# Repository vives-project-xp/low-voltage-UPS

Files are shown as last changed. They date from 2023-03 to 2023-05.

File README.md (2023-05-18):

# low-voltage-UPS

Project to make a low voltage UPS.
<!-- add better description -->

# Project Repository

This repository contains the source code and documentation for our project.

## Repository Structure

- `case`: Contains files related to the project's case design and 3D models.
- `esp-code`: Contains the code for the ESP micro controller used in the project.
- `frontend`: Contains the web frontend code for the project.
- `home-assistant`: Contains the configuration files for integrating the project with Home Assistant.
- `pcb`: Contains the PCB design files.
- `schemas`: Contains the schema diagrams for the project.

Link to video and ppt:
[Onedrive](https://vivesonline-my.sharepoint.com/:f:/g/personal/r0782899_student_vives_be/ErkIe6ZSpKdGq8MmYVde3NIBA33tiSL_xVnvaDJGF-avBQ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)

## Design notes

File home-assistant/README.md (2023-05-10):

# Home Assistant

## Introduction

This folder contains the files needed to add the low-voltage-UPS to the Home Assistant as a custom component.

To make it easier to read and understand, the documentation is split into three parts:

- [Development](development.md) (for developers)
- [Showcase](showcase.md) (for demonstration purposes)
- [Home Use](home-use.md) (for users)

The component isn't finished yet, so the documentation is still a work in progress.
Information about the component can be found in the [development](development.md) section.

## Images

### Adding the device to Home Assistant

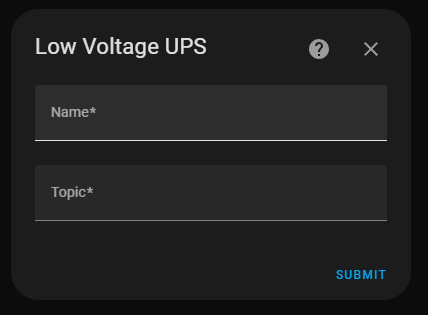
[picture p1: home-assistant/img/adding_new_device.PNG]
adding_new_device


### Overview of the device

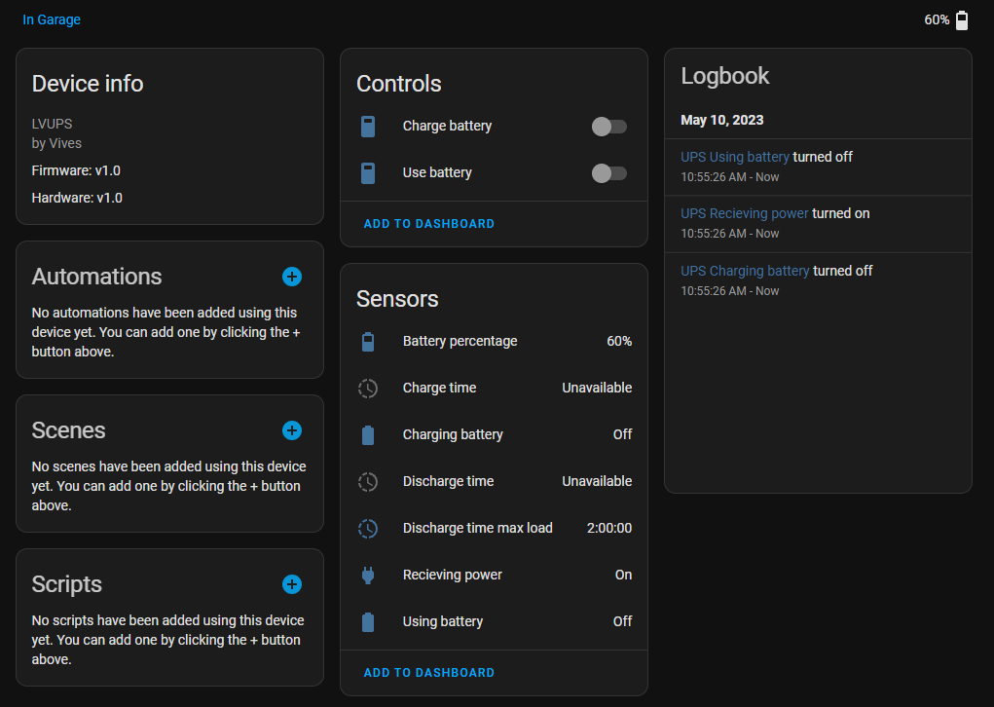
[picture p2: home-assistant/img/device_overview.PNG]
device_overview

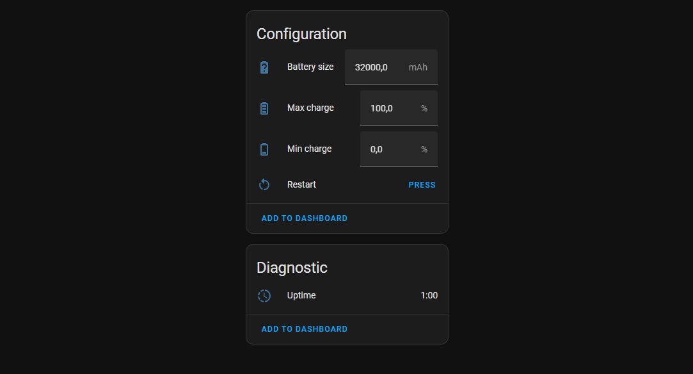
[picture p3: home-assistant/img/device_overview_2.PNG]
device_overview 2


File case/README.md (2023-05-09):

# Case

## Contents

Here is an overview of what this each folder contains:

- blender = the blender project and finished renders/clips
- inventor = the inventor project files for the case
- stl = an stl version of the case parts, useful for 3d printing

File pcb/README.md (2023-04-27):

# Circuit Board

## To do

1. vermogen verbruik van de aangesloten toestel.
2. gaten in de pcb maken.
3. kiezen tussen de batterij en net.
4. io pinnen maken 
5. soon^tm

## Schematic

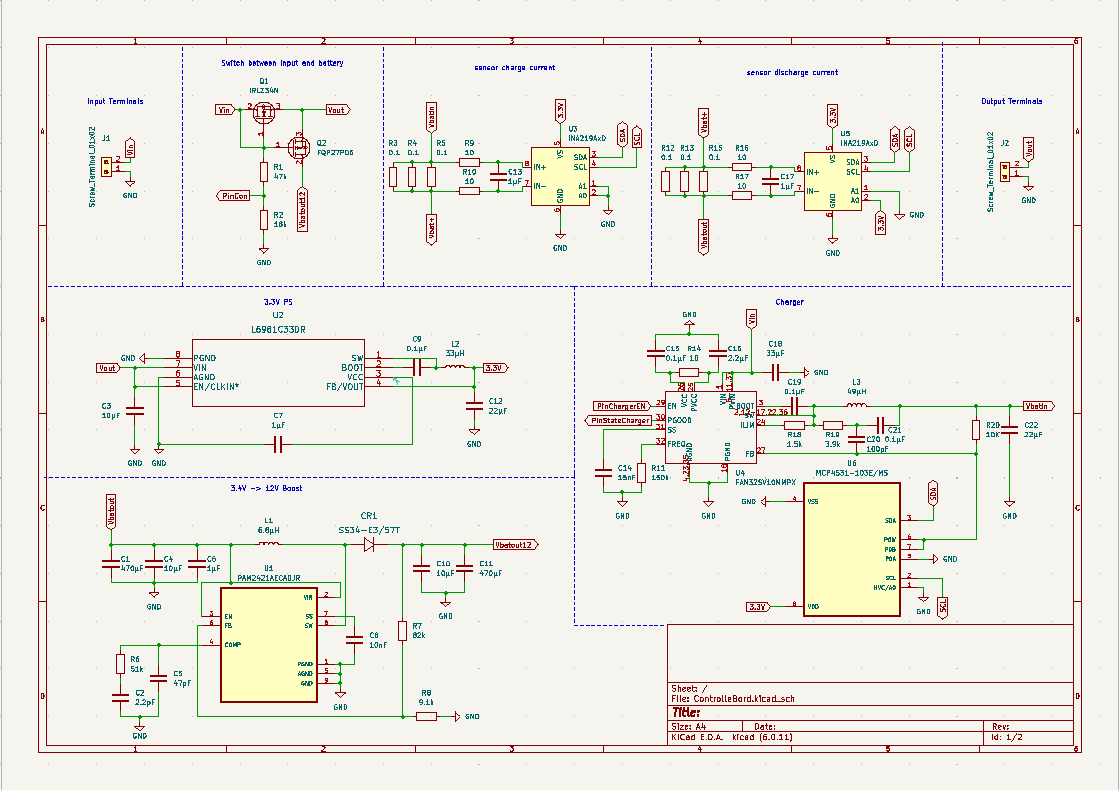
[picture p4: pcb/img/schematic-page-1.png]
SchematicPage1

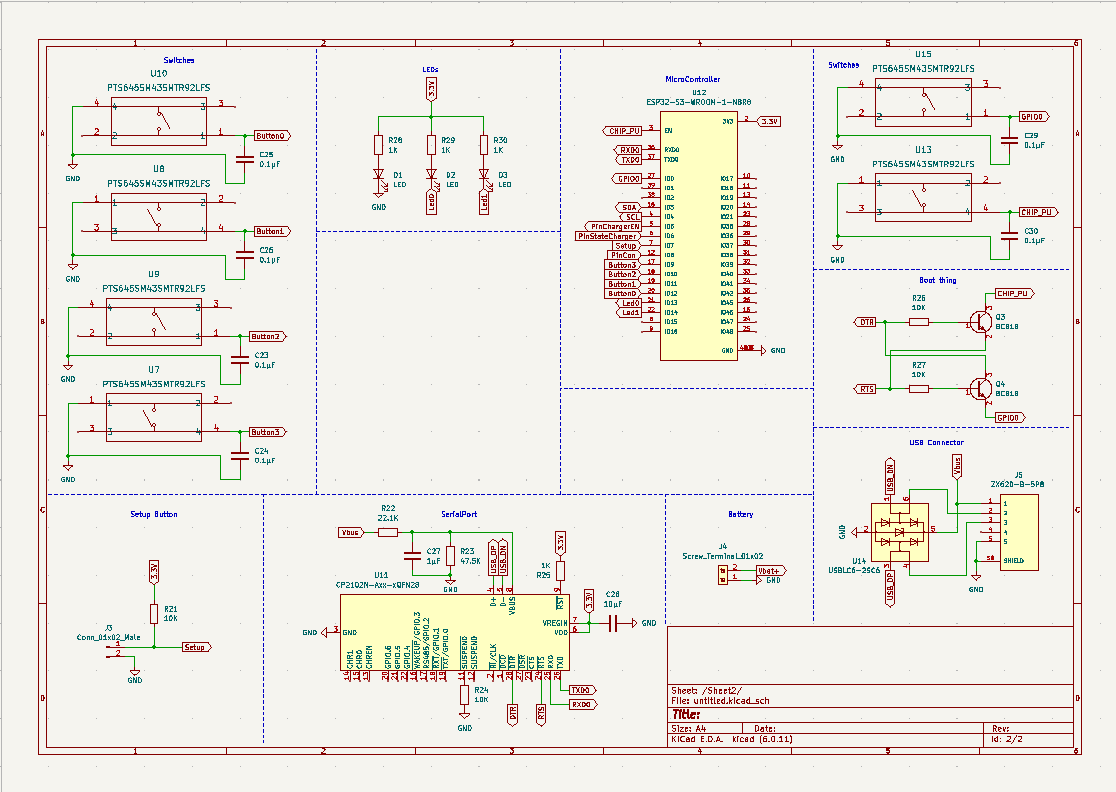
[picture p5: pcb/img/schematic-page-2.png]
SchematicPage2


## PCB

| Front | Back |
|---|---|
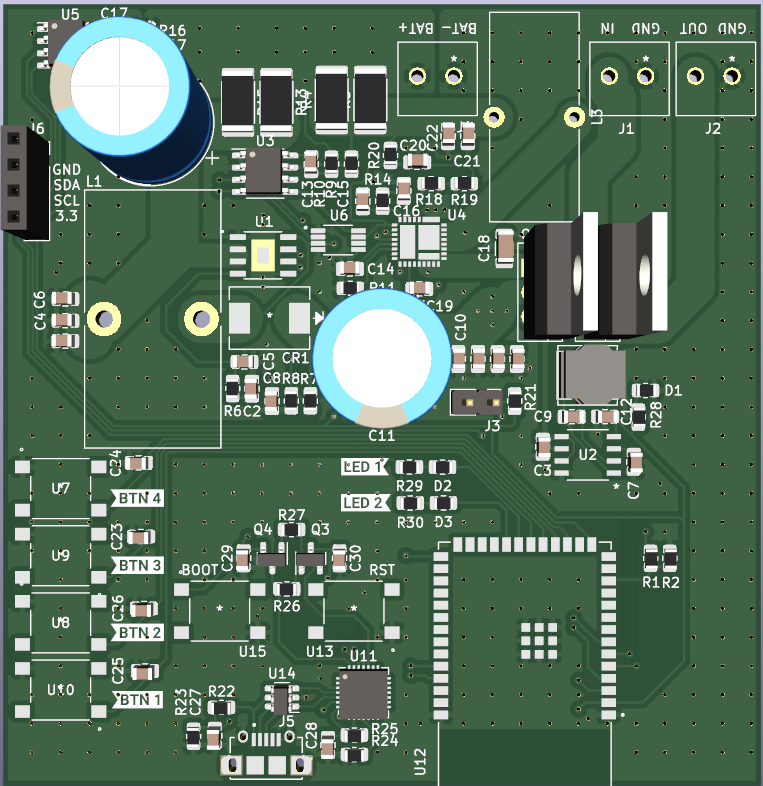
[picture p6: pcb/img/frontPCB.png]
PCB front
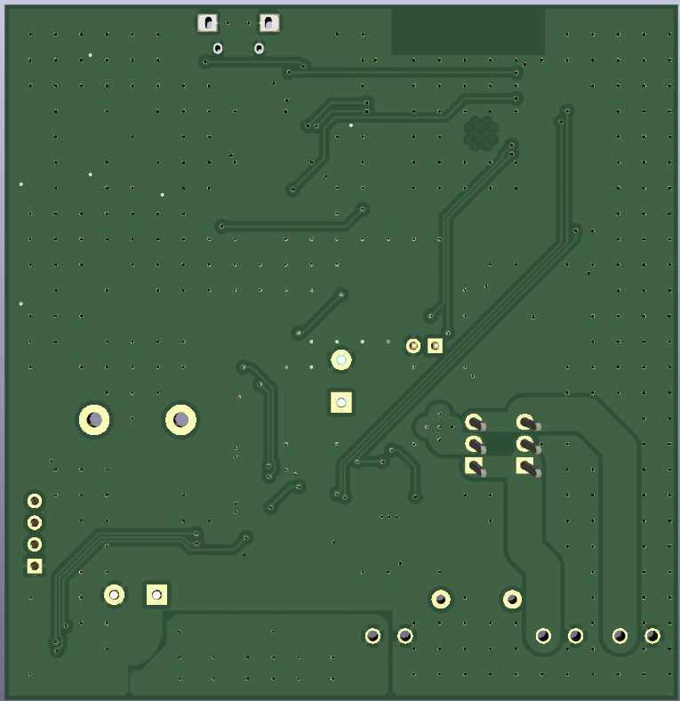
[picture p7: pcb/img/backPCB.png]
PCB Back
|  |  |

## BOM

The BOM or Bill of Materials consists out of a list of all the components with some of theire properties. 

| Designator | Quantity | Description | Footprint | Farnell ordercode | Price / unit |
|---|---|---|---|---|---|
| R25, R28-R30 | 4 | 1 kΩ | 0805 | [2073606](https://be.farnell.com/multicomp/mcmr08x1001ftl/res-1k-1-0-125w-0805-ceramic/dp/2073606) | 0,0165 € |
| R19 | 1 | 47.5 kΩ | 0805 | [2447665](https://be.farnell.com/multicomp/mcwr08x4752ftl/res-47k5-1-0-125w-thick-film/dp/2447665) | 0,0077 € |
| R18 | 1 | 22.1 kΩ | 0805 | [3496003](https://be.farnell.com/yageo/rc0805fr-0722k1l/res-22k1-1-0-125w-0805-thick-film/dp/3496003) | 0,029 € |
| R16, R17, R20, R22, R23 | 5 | 10 kΩ | 0805 | [1612522](https://be.farnell.com/bourns/cr0805-fx-1002elf/res-10k-1-0-125w-0805-thick-film/dp/1612522) | 0,029 € |
| R15 | 1 | 3.9 kΩ | 0805 | [2447654](https://be.farnell.com/multicomp/mcwr08x3901ftl/res-3k9-1-0-125w-thick-film/dp/2447654) | 0,0078 € |
| R14 | 1 | 1.5 kΩ | 0805 | [9333924](https://be.farnell.com/multicomp/mc01w080551k5/res-1k5-5-0-1w-0805-thick-film/dp/9333924) | 0,0153 € |
| R9 | 1 | 150 kΩ | 0805 | [2447573](https://be.farnell.com/multicomp/mcwr08x1503ftl/res-150k-1-0-125w-thick-film/dp/2447573) | 0,0078 € |
| R7, R8, R11-R13 | 5 | 10 Ω | 0805 | [2331768](https://be.farnell.com/te-connectivity/crgh0805j10r/res-10r-5-0-33w-0805-thick-film/dp/2331768) | 0,0132 € |
| R3-R5, R12, R13, R15 | 6 | 0.1 Ω | 0805 | [3994646](https://be.farnell.com/walsin/ww08xr100ftl/res-r100-0-125w-0805-thick-film/dp/3994646?st=shunt%20resistor) | 0,0302 € |
| R5 | 1 | 9.1 kΩ | 0805 | [2447739](https://be.farnell.com/multicomp/mcwr08x9101ftl/res-9k1-1-0-125w-thick-film/dp/2447739) | 0,0078 € |
| R4 | 1 | 82 kΩ | 0805 | [9237860](https://be.farnell.com/yageo/rc0805fr-0782kl/res-82k-1-0-125w-0805-thick-film/dp/9237860) | 0,029 € |
| R3 | 1 | 18 kΩ | 0805 | [2447584](https://be.farnell.com/multicomp/mcwr08x1802ftl/res-18k-1-0-125w-thick-film/dp/2447584) | 0,0078 € |
| R2 | 1 | 47 kΩ | 0805 | [9237836](https://be.farnell.com/yageo/rc0805fr-0747kl/res-47k-1-0-125w-0805-thick-film/dp/9237836) | 0,042 € |
| R1 | 1 | 51 kΩ | 0805 | [2447680](https://be.farnell.com/multicomp/mcwr08x5102ftl/res-51k-1-0-125w-0805-thick-film/dp/2447680) | 0,0081 € |
|---|---|---|---|---|---|
| C2 | 1 | 2.2 pF | 0805 | [3764575](https://be.farnell.com/yageo/cc0805crnpo9bn2r2/cap-2-2pf-50v-mlcc-0805/dp/3764575) | 0,0456 € |
| C5 | 1 | 47 pF | 0805 | [2812152](https://be.farnell.com/wurth-elektronik/885012007032/cap-47pf-25v-5-c0g-np0-0805/dp/2812152) | 0,047 € |
| C6, C7, C13, C17, C23 | 5 | 1μF | 0805 | [3873501](https://be.farnell.com/yageo/cc0805kkx6s8bb105/cap-1uf-25v-mlcc-0805/dp/3873501) | 0,0375 € |
| C8 | 1 | 10 nF | 0805 | [2534062](https://be.farnell.com/wurth-elektronik/885012207066/cap-0-01-f-25v-10-x7r-0805/dp/2534062) | 0,037 € |
| C3, C4, C10, C24 | 4 | 10 μF | 0805 | [3013452](https://be.farnell.com/samsung-electro-mechanics/cl21a106kaynnne/cap-10uf-25v-mlcc-0805/dp/3013452) | 0,073 € |
| C1, C11 | 1 | 470 μF | Radial Leaded | [9451439](https://be.farnell.com/multicomp/mcgpr50v477m13x21/cap-470-f-50v-20/dp/9451439) | 0,546 € |
| C12, C22 | 2 | 22 μF | 0805 | [1907510](https://be.farnell.com/murata/grm21br61e226me44l/cap-22-f-25v-20-x5r-0805/dp/1907510) | 0,178 € |
| C14 | 1 | 15 nF | 0805 | [2812419](https://be.farnell.com/wurth-elektronik/885012207067/cap-0-015-f-25v-10-x7r-0805/dp/2812419) | 0,0344 € |
| C9, C15, C19, C21, C23-C26, C29, C30 | 10 | 0.1 μF | 0805 | [2522443](https://be.farnell.com/kemet/c0805c104z3vactu/cap-0-1-f-25v-y5v-0805/dp/2522443) | 0,033 € |
| C16 | 1 | 2.2 μF | 0805 | [2073606](https://be.farnell.com/samsung-electro-mechanics/cl21a225kafnnne/cap-2-2uf-25v-mlcc-0805/dp/3013458) | 0,049 € |
| C18 | 1 | 33 μF | 1206 | [2525171](https://be.farnell.com/tdk/c3216x5r1e336m160ac/cap-33-f-25v-20-x5r-1206/dp/2525171) | 0,826 € |
| C20 | 1 | 100 pF | 0805 | [2812409](https://be.farnell.com/wurth-elektronik/885012207054/cap-100pf-25v-10-x7r-0805/dp/2812409) | 0,0468 € |
|---|---|---|---|---|---|
| J1, J2, J4 | 3 | 2 ways | screw terminal | [3810178](https://be.farnell.com/amphenol-anytek/yo0221500000g/tb-wire-to-brd-r-a-2way-16awg/dp/3810178) | 0,455 € |
|---|---|---|---|---|---|
| U7-U10, U13, U15 | 6 | Switch | Switch | [2320087](https://be.farnell.com/c-k-components/pts645sm43smtr92lfs/switch-spst-0-05a-12vdc-smd-4/dp/2320087) | 0,25 € |
|---|---|---|---|---|---|
| J5 | 1 | USB connector | USB | [2554980](https://be.farnell.com/hirose-hrs/zx62d-b-5p8-30/micro-usb-2-0-type-b-rcpt-smt/dp/2554980?st=zx62d-b-5p8) | 0,846 € |
| U14 | 1 | ESD Protection Device | SOT-23 | [2290332](https://be.farnell.com/kingbright/kp-2012seck/led-0805-250mcd-orange/dp/2290332) | 0,159 € |
|---|---|---|---|---|---|
| SR1 | 1 | diode | DO-214 | [2101195](https://be.farnell.com/multicomp/ss34a/diode-rectifier-3a-40v-do-214ac/dp/2101195?st=ss34) | 0,401 € |
| D1 - D3 | 3 | led | 0805 | [2101195](https://be.farnell.com/multicomp/ss34a/diode-rectifier-3a-40v-do-214ac/dp/2101195?st=ss34) | 0,401 € |
|---|---|---|---|---|---|
| U6 | 1 | I2c potentiometer | MSOP | [8737606](https://be.farnell.com/microchip/mcp4531-103e-ms/dpot-single-7bit-v-i2c-8msop/dp/1698946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) |0,40 € |
|---|---|---|---|---|---|
| L1 | 1 | 6.8 μH | YUP | [3518424](https://nl.farnell.com/wurth-elektronik/7447720068/inductor-6-8uh-unshielded-3-9a/dp/3518424) | € 0,756 |
| L2 | 1 | 33 μH | YUP | [2061655](https://nl.farnell.com/bourns/srn6045-330m/inductor-33uh-semi-shielded-power/dp/2061655) | € 0,408 |
| L3 | 1 | 49 μH | YUP | [3517136](https://nl.farnell.com/wurth-elektronik/744132/toroidal-inductor-49uh-5-8a-tht/dp/3517136) | € 2,56 |
|---|---|---|---|---|---|
| U3, U5 | 1 | 10 kΩ | SOIC | [3517136](https://be.farnell.com/texas-instruments/ina219bidr/current-power-monitor-11khz-soic/dp/3118166?st=ina219) | 2,96 € |
|---|---|---|---|---|---|
| U1 | 1 | Buck | SOIC | [3755444](https://be.farnell.com/diodes-inc/pam2421aecadjr/dc-dc-conv-boost-520khz-40-to/dp/3755444?st=pam2421) | 0,90 € |
| U2 | 1 | Buck| SOIC | [4064213](https://be.farnell.com/stmicroelectronics/l6981c33dr/dc-dc-conv-sync-buck-400khz-150deg/dp/4064213?st=l6981c) | 3,02 € |
| U4 | 1 | Buck | QFN-34 | [2355372](https://be.farnell.com/onsemi/fan23sv10mmpx/buck-synch-adj-10a-1-5mhz-34pqfn/dp/2355372?st=fan23sv10m) | 1,72 € |
|---|---|---|---|---|---|
| Q2 | 1 | P-kanaal | TO-220 | [8648620](https://be.farnell.com/infineon/irf9540npbf/mosfet-p-100v-23a-to-220/dp/8648620) | 1,55 € |
| Q1 | 1 | N-kanaal | TO-220 | [2547307](https://be.farnell.com/vishay/irfz34pbf/mosfet-n-ch-60v-30a-to-220ab-3/dp/2547307) | 1,96 € |

Total price: 65,03 €

| Designator | Quantity | Description | Footprint | Mouser ordercode | Price / unit |
|---|---|---|---|---|---|
| U12 | 1 | ESP32-S3 | ESP32 | [C2913202](https://www.lcsc.com/product-detail/WiFi-Modules_Espressif-Systems-ESP32-S3-WROOM-1-N16R8_C2913202.html) | € 4.83 |
| U11 | 1 | CP2102NA02GQFN28 | QFN28 | [C964632](https://www.lcsc.com/product-detail/USB-ICs_SILICON-LABS-CP2102N-A02-GQFN28R_C964632.html) | € 2.60 |

Total price: €10.26

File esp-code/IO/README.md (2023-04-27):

# IO documentation

# How some IC`s work.

1. INA219
2. MCP4531 

# The INA219

The INA219 is a ic that Calculates the current and measures the voltage.

## I2C Address

1. The 7 bit address for the charge current sensor is 0b1000000
2. The 7 bit address for the discharge current sensor is 0b1000001

## The data registers

### The Config Register address 0x00.

| MSB | 14 | 13 | 12  | 11  | 10 | 9 | 8 | 7 | 6 | 5 | 4 | 3 | 2 | 1 | LSB |
|-----|----|---|-----|-----|---|---|---|---|---|---|---|---|---|---|---|
| RST | — | BRNG | PG1 | PG0 | BADC 3 | BADC 2 | BADC 1 | BADC 0 | SADC 3 | SADC 2 | SADC 1 | SADC 0 | MODE 2 | MODE 1 | MODE 0 |
| 0 | 0  | 0 | 1 | 0 | 1 | 0 | 0 | 0 | 1 | 0 | 0 | 0 | 1 | 1 | 1 |
| 0 | 0  | 0 | 1 | 0 | 1 | 1 | 0 | 1 | 1 | 1 | 0 | 1 | 1 | 1 | 1 |

We have 2 different values. The first makes only one sample and saves it in the register. The second makes 128 monsters and calculates the average and saves it in the register.

More info see the data sheet.

The values in Hex are 0x1447 or 0x16EF

***

### The Shunt voltage register address 0x01.

| MSB  | 14 | 13 | 12 | 11 | 10 | 9 | 8 | 7 | 6 | 5 | 4 | 3 | 2 | 1 | LSB |
|---|---|---|---|---|---|---|---|---|---|---|---|---|---|---|---|
| SIGN | SIGN | SD13_4 | SD12_4 | SD11_4 | SD10_4 | SD9_4 | SD8_4 | SD7_4 | SD6_4 | SD5_4 | SD4_4 | SD3_4 | SD2_4 | SD1_4 | SD0_4 |

The 2 MSB are the sign. The 14 following bits are the voltage in decimal. To get the real value you need to divide by 100 to get the voltage in mV.

***

### The V-bus register address 0x02.

| MSB  | 14 | 13 | 12  | 11  | 10  | 9 | 8 | 7 | 6 | 5 | 4 | 3 | 2 | 1 | LSB |
|---|---|---|-----|-----|-----|-----|-----|-----|-----|-----|-----|-----|---|---|-----|
| BD12 | BD11 | BD10 | BD9 | BD8 | BD7 | BD6 | BD5 | BD4 | BD3 | BD2 | BD1 | BD0 | — | CNVR | OVF |

The 13 MSB are the voltage value to get the real voltage you need to multiply it with 4mV.

***

### The Power Register address 0x03.

We wont use this one.

***

### The Current Register address 0x04.

| MSB | 14 | 13 | 12 | 11 | 10 | 9 | 8 | 7 | 6 | 5 | 4 | 3 | 2 | 1 | LSB |
|---|---|---|---|---|---|-----|-----|-----|-----|-----|-----|-----|-----|-----|-----|
| CSIGN | CD14 | CD13 | CD12 | CD11 | CD10 | CD9 | CD8 | CD7 | CD6 | CD5 | CD4 | CD3 | CD2 | CD1 | CD0 |

To get the real value you need to multiply by $I_{LSB} =  \tfrac{I_{max}}{2^{15}}$.

In our case is $I_{max}$ 10A so the LSB is $305\mu A$.

***

### The Calibration Register address 0x05.

| MSB  | 14 | 13 | 12 | 11 | 10 | 9 | 8 | 7 | 6 | 5 | 4 | 3 | 2 | 1 | LSB |
|---|---|---|---|---|---|-----|-----|-----|-----|-----|-----|-----|-----|-----|-----|
| FS15 | FS14 | FS13 | FS12 | FS11 | FS10 | FS9 | FS8 | FS7 | FS6 | FS5 | FS4 | FS3 | FS2 | FS1 | FS0 |

To calculate the Calibration Value you need this equation: 

$ Cal = trunc \left( \tfrac{0.04096}{I_{LSB}  * R_{SHUNT}} \right) $

In our case using 2 shunt resistor in parallel and resistent of  $0.01\Omega$ each is the value 0x68DB.

***

# MCP4531

## I2C Address

1. The 7 bit address for the digital potentiometer is 0b0101110

## The data registers

### Wiper 0 0x00

write 10 bits of data MSB wil be ignored only 9 will be saved.

read 2 Bytes and only the last 10 bits have data.

### some screenshots.

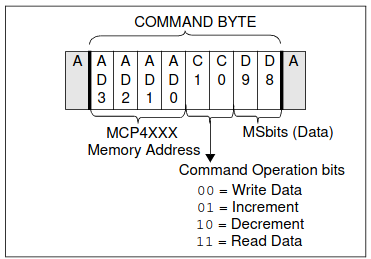
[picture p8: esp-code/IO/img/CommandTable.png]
CommandTable

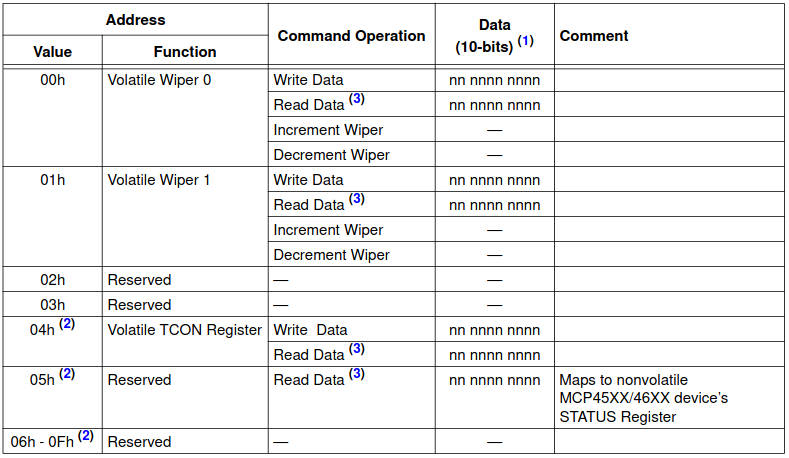
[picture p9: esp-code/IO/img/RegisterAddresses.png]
RegisterAddresses

WriteCommand
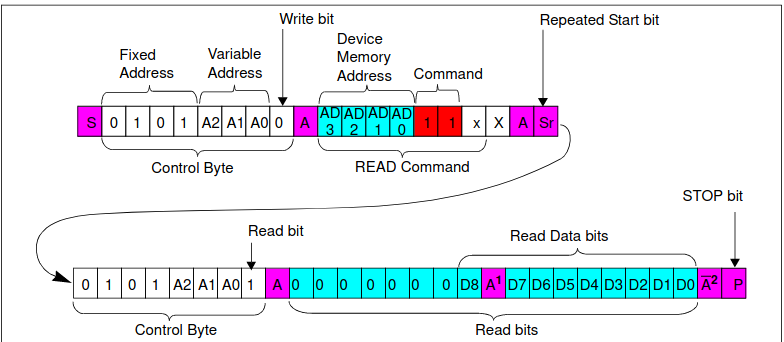
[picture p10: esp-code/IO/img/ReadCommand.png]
ReadCommand


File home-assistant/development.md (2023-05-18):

# Development

## List of contents

1. [Installation](#1-installation)
    1. [Setup Development Environment](#11-setup-development-environment)
    2. [Add the custom component to Home Assistant](#12-add-the-custom-component-to-home-assistant)
        1. [Add the component to the custom_components folder](#121-add-the-component-to-the-custom_components-folder)
        2. [Add the component to the components folder](#122-add-the-component-to-the-components-folder)
2. [Usage](#2-usage)
3. [Testing](#3-testing)
4. [The lvups component](#4-the-lvups-component)
    1. [Device information](#41-device-information)
    2. [File structure and relations](#42-file-structure-and-relations)

## 1. Installation

### 1.1 Setup Development Environment

Before we can start developing, we need our development environment to be set up.  
To do this follow the steps provided by the Home Assistant developer documentation, which can be found [here](https://developers.home-assistant.io/docs/development_environment/).

Once the development environment is set up, we can add our custom component to Home Assistant.

**Note:**  
Don't forget to run the `Install all requirements` task in Visual Studio Code, this will install all the required dependencies for Home Assistant.

### 1.2 Add the custom component to Home Assistant

**There are two ways to do this:**

- Add the component to the custom_components folder (drag and drop, easier for testing)
- Add the component to the components folder (some extra steps, easier for development)

**So what's the difference between these two methods?**  

Both methods will add the component to your Home Assistant installation, but there are some differences.

When you add the component to the custom_components folder, Home Assistant will try to load the component from this folder and expect it to work.
If you have a component that just needs some testing, this is the easiest way to do it.  
The config folder is not part of the Home Assistant repository, because it contains all the user specific configurations.  
This means that if you add your component to this folder, any changes you make to the component will not be tracked by git.

When you add the component to the components folder, Home Assistant will handle the component as a built-in component.
If you're developing a component that you want to add to Home Assistant, this is the way to go.
This gives you the benefits of the Home Assistant development tools, like translation, unit tests, etc.
But also means that your code needs to follow the Home Assistant Rules and Guidelines before you can commit it to your fork.

#### 1.2.1 Add the component to the custom_components folder

1. Go to the config folder of your Home Assistant installation and create a new folder called `custom_components` (if it doesn't exist already).
2. In this folder just drag and drop the content of the `component` folder from this repository.

That's it, the component is now added to your Home Assistant installation.

#### 1.2.2 Add the component to the components folder

1. Open a terminal in the root of your Home Assistant installation.
2. Run the following command: `python3 -m script.scaffold integration`. (This script will create a new component in the components folder.)
3. Fill in the following information when prompted (for this component):
    - What is the domain?
        > `lvups`

    - What is the name of your integration?
        > `Low Voltage UPS`

    - What is your GitHub handle?
        > `??` (your GitHub username, @username)

    - What PyPI package and version do you depend on? Leave blank for none.
        > (We are not using any dependencies, so leave this blank)

    - How will your integration gather data?
        > `local_push` (We update the state when the device pushes an update, so we don't need to poll the device)

    - Does Home Assistant need the user to authenticate to control the device/service? (yes/no) [yes]
        > `no` (We don't need to authenticate to control the device)

    - Is the device/service discoverable on the local network? (yes/no) [no]
        > `no` (The device is not discoverable on the local network)

    - Is this a helper integration? (yes/no) [no]
        > `no` (This is not a helper integration)

    - Can the user authenticate the device using OAuth2? (yes/no) [no]
        > `no` (We are using mqtt, so we don't need OAuth2)

4. Wait for the script to finish. (Home Assistant will create all the necessary files for you)
5. Open the folder `homeassistant/components/lvups` in your favorite editor.
6. Replace the contents of the folder with the contents of the `component/lvups` folder from this repository.

That's it, the component is now added to your Home Assistant installation.

## 2. Usage

Now that the component is added to your Home Assistant installation, you can start using/developing it.  
More information about developing custom components can be found [here](https://developers.home-assistant.io/docs/creating_component_index).

## 3. Testing

When you want to test the code, you can spin up a Home Assistant instance with the custom component installed.  
If your using Visual Studio Code, you can simply press `F5` to start a Home Assistant instance.

**Note:**  
When this is the first time you are starting Home Assistant, it will require you to do the initial setup, just like a normal Home Assistant installation.  
This means that you will need to create a user, set a password, etc.

## 4. The lvups component

### 4.1 Device information

The lvups device has the following attributes:

controls:

- `Charge battery`: A switch that can be used to tell the device it should charge the battery. (default: `off`)
- `Use battery`: A switch that can be used to tell the device it should use the battery, when recieving grid power. (default: `off`)

sensors:

- `Battery percentage`: A sensor that shows the current battery percentage.
- `Charge time`: A sensor that shows the time left until the battery is fully charged, estimate. (When charging)
- `Discharge time`: A sensor that shows the time left until the battery is fully discharged, estimate. (When discharging)
- `Discharge time max load`: A sensor that shows the time left until the battery is fully discharged, estimate on max load. (Always shown)
- `Charging battery`: A sensor that shows if the battery is currently charging.
- `Using battery`: A sensor that shows if the battery is currently being used.
- `Recieving power`: A sensor that shows if the device is currently recieving power from the grid.

Configuration:

- `Battery size`: The capacity of the battery in mAh. (default: `0`)
- `Max charge`: The maximum percentage the battery can be charged to. (default: `100`)
- `Min charge`: The minimum percentage the battery can be discharged to. (default: `0`)
- `Restart`: A button that can be used to restart the device.

Diagnostic:

- `Uptime`: The time the device has been running, in `hours:minutes:seconds` format.

### 4.2 File structure and relations

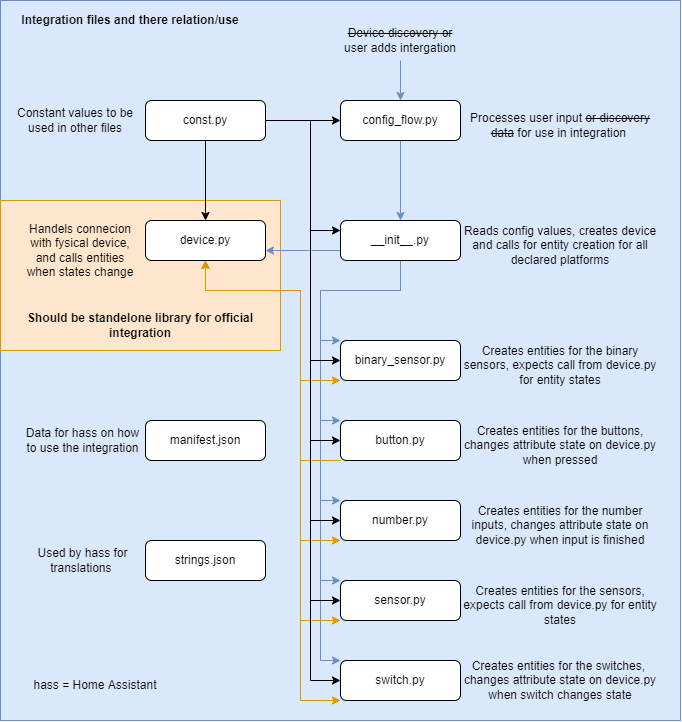
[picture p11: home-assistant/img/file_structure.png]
schema of the file structure


### 4.2 Todo

- [ ] Add mqtt discovery
- [ ] Add LWT (last will and testament)
- [ ] Add unit tests (for device and config flow)
- [ ] Change translations (on/off -> charging/discharging, etc.)
- [ ] Add more sensors, switches, etc. (depends on the hardware)
- [ ] Move device code to a library (as needed by the Home Assistant Rules and Guidelines)
- [ ] Make the code comply with the Home Assistant Rules and Guidelines (so it may someday be added to Home Assistant)

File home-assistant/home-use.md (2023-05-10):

# Home Use

## List of contents

1. [Installation](#1-installation)
    1. [Setup Home Assistant](#11-setup-home-assistant)
    2. [Add the custom component](#12-add-the-custom-component)
        1. [Home Assistant Container](#121-home-assistant-container)
        2. [Home Assistant Operating System](#122-home-assistant-operating-system)
    3. [Add lvups device to Home Assistant](#13-add-lvups-device-to-home-assistant)
2. [Usage](#2-usage)

## 1. Installation

### 1.1 Setup Home Assistant

For installation instructions, see the [home assistant documentation](https://www.home-assistant.io/installation/).

**Note:**
Make sure you also have mqtt running either in a container or as an addon.

### 1.2 Add the custom component

#### 1.2.1 Home Assistant Container

If your running Home Assistant Container, you can add the component to your installation by following these steps:

1. Make sure Home Assistant is not running.
2. Make sure you have cloned this repository to your local machine and are in the home-assistant directory.
3. Run the following command:
    ```docker cp ./component/ <container_name>:/config/custom_components/```.
    (replace `<container_name>` with the name of your Home Assistant Container)
4. Start Home Assistant.

That's it, the component is now added to your Home Assistant installation.

#### 1.2.2 Home Assistant Operating System

If your running Home Assistant Operating System, you can add the component to your installation by following these steps:

1. In your Home Assisant instance, go to Settings > Add-ons.
2. Under the Official add-ons section, you will find the File editor add-on.
3. Click on File editor and click on Install. When the installation is complete, the UI will go to the add-on details page for the file editor.
4. Now start the add-on by clicking on Start.
5. Open the user interface by clicking on Open Web UI.
6. In the File editor, go to the config folder of your Home Assistant installation and create a new folder called `custom_components` (if it doesn't exist already).
7. In this folder just drag and drop the content of the `component` folder from this repository.
8. Restart Home Assistant.

That's it, the component is now added to your Home Assistant installation.

### 1.3 Add lvups device to Home Assistant

Now you can add a lvups device to your Home Assistant installation.
This can be done by going to Setting > Devices & services and clicking on the Add Integration button.

Now search for lvups and click on the lvups integration.
Fill in the required information and click on Submit.

That's it, the lvups device is now added to your Home Assistant installation.

**Note:**
Make sure you have added your mqtt broker to Home Assistant before adding the lvups device else it will not work. For more info about this, see the [MQTT documentation](https://www.home-assistant.io/integrations/mqtt/).

## 2. Usage

Now that we have a working Home Assistant installation with the lvups component installed, we can start using it.

### 2.1 Device info

The lvups device has the following attributes:

controls:

- `Charge battery`: A switch that can be used to tell the device it should charge the battery. (default: `off`)
- `Use battery`: A switch that can be used to tell the device it should use the battery, when recieving grid power. (default: `off`)

sensors:

- `Battery percentage`: A sensor that shows the current battery percentage.
- `Charge time`: A sensor that shows the time left until the battery is fully charged, estimate. (When charging)
- `Discharge time`: A sensor that shows the time left until the battery is fully discharged, estimate. (When discharging)
- `Discharge time max load`: A sensor that shows the time left until the battery is fully discharged, estimate on max load. (Always shown)
- `Charging battery`: A sensor that shows if the battery is currently charging.
- `Using battery`: A sensor that shows if the battery is currently being used.
- `Recieving power`: A sensor that shows if the device is currently recieving power from the grid.

Configuration:

- `Battery size`: The capacity of the battery in mAh. (default: `0`)
- `Max charge`: The maximum percentage the battery can be charged to. (default: `100`)
- `Min charge`: The minimum percentage the battery can be discharged to. (default: `0`)
- `Restart`: A button that can be used to restart the device.

Diagnostic:

- `Uptime`: The time the device has been running, in `hours:minutes:seconds` format.

### 2.2 Automation examples

Here are some automation examples that you can use:

- Get a notification when there is no power going to the device (possible grid power loss):

    ```text
        trigger:
            - UPS recieving power: 'off'
        action:
            - Call notify service with message: 'Grid power loss'
    ```

- Charge bettery when solar power is avaialble: (example made using cdem for getting data from smartmeter)

    ```text
        trigger:
            - cdem power production: '> 0'
        condition:
            - UPS battery percentage: '< 100'
        action:
            - UPS charge battery: 'on'
    ```

- Use battery when grid power uses high tarif: (also using the cdem component)

    ```text
        trigger:
            - cdem tarif: 'high'
        condition:
            - UPS battery percentage: '> 50'
        action:
            - UPS use battery: 'on'
    ```

## 3. Troubleshooting

- When performing a firmware update, you will need to reload the lvups device in Home Assistant to see the new firmware version.

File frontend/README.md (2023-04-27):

# Nuxt 3 Minimal Starter

Look at the [Nuxt 3 documentation](https://nuxt.com/docs/getting-started/introduction) to learn more.

## Preview

Current version of the deployed application is available at [https://ups.robcocquyt.be](https://ups.robcocquyt.be/)

## Setup

Make sure to install the dependencies using npm:

```bash
npm install
```

## Development Server

Start the development server on http://localhost:3000

```bash
npm run dev
```

## Production

Build the application for production:

```bash
npm run build
```

Locally preview production build:

```bash
npm run preview
```

Check out the [deployment documentation](https://nuxt.com/docs/getting-started/deployment) for more information.

## Used Packages

- [Nuxt 3](https://v3.nuxtjs.org/)
- [Tailwind css](https://tailwindcss.com)
- [Daisy UI](https://daisyui.com/)
- [Nuxt Icon](https://github.com/nuxt-modules/icon)

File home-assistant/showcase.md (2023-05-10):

# Showcase

## List of contents

1. [Installation](#1-installation)
    1. [Requirements](#11-requirements)
    2. [Setup containers](#12-setup-containers)
    3. [Configure Home Assistant](#13-configure-home-assistant)

2. [Usage](#2-usage)

## 1. Installation

### 1.1 Requirements

Before you can run the showcase, you need to install the following dependencies:

- Docker

### 1.2 Setup containers

To setup the containers, follow the steps below:

1. Make sure docker is running.
2. Open a terminal in the `showcase` directory.
3. Run the following command in the terminal:

    ```bash
    docker-compose up
    ```

4. Wait for the containers to start.
5. Now we copy the component to the Home Assistant container, run the following command in the terminal:

    ```bash
    docker cp ../component/ homeassistant:/config/custom_components
    ```

6. Restart the Home Assistant container.

### 1.3 Configure Home Assistant

After the containers are started, got to the Home Assistant web interface using the following [link](http://localhost:8123).  
Now you can configure Home Assistant to your liking, for more info about this, see the [Home Assistant documentation](https://www.home-assistant.io/docs/).  
We also need to add our mqtt broker to Home Assistant, for more info about this, see the [MQTT documentation](https://www.home-assistant.io/integrations/mqtt/).  
The mqtt broker is available at `mosquitto:1883`.

## 2. Usage

After setting up the environment, you should have a working Home Assistant installation with the low-voltage-UPS component installed.
Now you simply need to add a low-voltage-UPS device to your Home Assistant installation, for more info about this, see the [Home Assistant documentation](https://www.home-assistant.io/docs/configuration/devices/).

For automation examples, please look at the [Home-Use](home-use.md) section.

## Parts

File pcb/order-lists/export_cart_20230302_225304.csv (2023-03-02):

LCSC Part Number | Manufacture Part Number | Manufacturer | Package | Customer # | Description | RoHS | Order Qty. | Min\Mult Order Qty. | Unit Price | Order Price | Product Link
C2913202 | ESP32-S3-WROOM-1-N16R8 | Espressif Systems | SMD,18x25.5mm |  | SMD,18x25.5mm WiFi Modules ROHS | yes | 1 | 1 | 4.8293 | 4.83 | https://assets.lcsc.com/images/lcsc/96x96/20230123_Espressif-Systems-ESP32-S3-WROOM-1-N16R8_C2913202_front.jpg
C964632 | CP2102N-A02-GQFN28R | SILICON LABS | QFN-28-EP(5x5) |  | QFN-28-EP(5x5) USB ICs ROHS | yes | 1 | 1 | 2.5955 | 2.60 | https://assets.lcsc.com/images/lcsc/96x96/20230202_SILICON-LABS-CP2102N-A02-GQFN28R_C964632_front.jpg

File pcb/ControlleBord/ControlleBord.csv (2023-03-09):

Source: | /home/gibi500/Vives/projectWeek/pcb/ControlleBord/ControlleBord.kicad_sch
Date: | Thu 02 Mar 2023 10:11:45 AM CET
Tool: | Eeschema (6.0.11)
Generator: | /usr/share/kicad/plugins/bom_csv_grouped_by_value.py
Component Count: | 75
Individual Components:
Item | Qty | Reference(s) | Value | LibPart | Footprint | Datasheet | MANUFACTURER | MAXIMUM_PACKAGE_HEIGHT | MF | Manufacturer | PARTREV | Package | SNAPEDA_PN | STANDARD
 |  | C1 | 470μF | Device:C | Capacitor_THT:CP_Radial_D13.0mm_P5.00mm | ~
 |  | C2 | 2.2pF | Device:C | Capacitor_SMD:C_0805_2012Metric | ~
 |  | C3 | 10μF | Device:C | Capacitor_SMD:C_0805_2012Metric | ~
 |  | C4 | 10μF | Device:C | Capacitor_SMD:C_0805_2012Metric | ~
 |  | C5 | 47pF | Device:C | Capacitor_SMD:C_0805_2012Metric | ~
 |  | C6 | 1μF | Device:C | Capacitor_SMD:C_0805_2012Metric | ~
 |  | C7 | 1μF | Device:C | Capacitor_SMD:C_0805_2012Metric | ~
 |  | C8 | 10nF | Device:C | Capacitor_SMD:C_0805_2012Metric | ~
 |  | C9 | 100nF | Device:C | Capacitor_SMD:C_0805_2012Metric | ~
 |  | C10 | 10μF | Device:C | Capacitor_SMD:C_0805_2012Metric | ~
 |  | C11 | 470μF | Device:C | Capacitor_THT:CP_Radial_D13.0mm_P5.00mm | ~
 |  | C12 | 22μF | Device:C | Capacitor_SMD:C_0805_2012Metric | ~
 |  | C13 | 1μF | Device:C | Capacitor_SMD:C_0805_2012Metric | ~
 |  | C14 | 15nF | Device:C | Capacitor_SMD:C_0805_2012Metric | ~
 |  | C15 | 0.1μF | Device:C | Capacitor_SMD:C_0805_2012Metric | ~
 |  | C16 | 2.2μF | Device:C | Capacitor_SMD:C_0805_2012Metric | ~
 |  | C17 | 1μF | Device:C | Capacitor_SMD:C_0805_2012Metric | ~
 |  | C18 | 33μF | Device:C | Capacitor_SMD:C_1206_3216Metric | ~
 |  | C19 | 0.1μF | Device:C | Capacitor_SMD:C_0805_2012Metric | ~
 |  | C20 | 100pF | Device:C | Capacitor_SMD:C_0805_2012Metric | ~
 |  | C21 | 0.1μF | Device:C | Capacitor_SMD:C_0805_2012Metric | ~
 |  | C22 | 22μF | Device:C | Capacitor_SMD:C_0805_2012Metric | ~
 |  | C23 | 1μF | Device:C | Capacitor_SMD:C_0805_2012Metric | ~
 |  | C24 | 10μF | Device:C | Capacitor_SMD:C_0805_2012Metric | ~
 |  | C25 | 0.1μF | Device:C | Capacitor_SMD:C_0805_2012Metric | ~
 |  | C26 | 0.1μF | Device:C | Capacitor_SMD:C_0805_2012Metric | ~
 |  | CR1 | SS34-E3/57T | 2023-02-22_21-35-58:SS34-E3{slash}57T | footprints1.0:SS34-E3&slash_57T
 |  | D1 | PESD5V0L1BA,115 | Diode:ESD9B5.0ST5G | Diode_SMD:D_SOD-323 | https://www.onsemi.com/pub/Collateral/ESD9B-D.PDF
 |  | D2 | PESD5V0L1BA,115 | Diode:ESD9B5.0ST5G | Diode_SMD:D_SOD-323 | https://www.onsemi.com/pub/Collateral/ESD9B-D.PDF
 |  | D3 | PESD5V0L1BA,115 | Diode:ESD9B5.0ST5G | Diode_SMD:D_SOD-323 | https://www.onsemi.com/pub/Collateral/ESD9B-D.PDF
 |  | J1 | Screw_Terminal_01x02 | Connector:Screw_Terminal_01x02 | footprints3.0:YO0221500000G | ~
 |  | J2 | Screw_Terminal_01x02 | Connector:Screw_Terminal_01x02 | footprints3.0:YO0221500000G | ~
 |  | J3 | Conn_01x02_Male | Connector:Conn_01x02_Male | Connector_PinHeader_2.54mm:PinHeader_1x02_P2.54mm_Vertical | ~
 |  | J4 | Screw_Terminal_01x02 | Connector:Screw_Terminal_01x02 | footprints3.0:YO0221500000G | ~
 |  | J5 | ZX62D-B-5P8 | ZX62D-B-5P8:ZX62D-B-5P8 | Kicad:HRS_ZX62D-B-5P8 |  |  |  | Hirose Electric |  | N/A |  |  | Manufacturer Recommendations
 |  | L1 | 6.8μH | Device:L | Inductor_THT:L_Toroid_Vertical_L26.7mm_W14.0mm_P10.16mm_Pulse_D | ~
 |  | L2 | 33μH | Device:L | Inductor_SMD:L_Bourns_SRN6045TA | ~
 |  | L3 | 49μH | Device:L | Inductor_THT:L_Toroid_Vertical_L21.6mm_W9.1mm_P8.40mm_Bourns_5700 | ~
 |  | Q1 | IRLZ34N | Transistor_FET:IRLZ34N | Package_TO_SOT_THT:TO-220-3_Vertical | http://www.infineon.com/dgdl/irlz34npbf.pdf?fileId=5546d462533600a40153567206892720
 |  | Q2 | FQP27P06 | Transistor_FET:FQP27P06 | Package_TO_SOT_THT:TO-220-3_Vertical | https://www.onsemi.com/pub/Collateral/FQP27P06-D.PDF
 |  | Q3 | BC818 | Transistor_BJT:BC818 | Package_TO_SOT_SMD:SOT-23 | https://www.onsemi.com/pub/Collateral/BC818-D.pdf
 |  | Q4 | BC818 | Transistor_BJT:BC818 | Package_TO_SOT_SMD:SOT-23 | https://www.onsemi.com/pub/Collateral/BC818-D.pdf
 |  | R1 | 51k | Device:R | Resistor_SMD:R_0805_2012Metric | ~
 |  | R2 | 47k | Device:R | Resistor_SMD:R_0805_2012Metric | ~
 |  | R3 | 18k | Device:R | Resistor_SMD:R_0805_2012Metric | ~
 |  | R4 | 82k | Device:R | Resistor_SMD:R_0805_2012Metric | ~
 |  | R5 | 9.1k | Device:R | Resistor_SMD:R_0805_2012Metric | ~
 |  | R6 | R_Shunt | Device:R_Shunt | Package_TO_SOT_THT:TO-220-2_Vertical | ~
 |  | R7 | 10 | Device:R | Resistor_SMD:R_0805_2012Metric | ~
 |  | R8 | 10 | Device:R | Resistor_SMD:R_0805_2012Metric | ~
 |  | R9 | 150k | Device:R | Resistor_SMD:R_0805_2012Metric | ~
 |  | R10 | R_Shunt | Device:R_Shunt | Package_TO_SOT_THT:TO-220-2_Vertical | ~
 |  | R11 | 10 | Device:R | Resistor_SMD:R_0805_2012Metric | ~
 |  | R12 | 10 | Device:R | Resistor_SMD:R_0805_2012Metric | ~
 |  | R13 | 10 | Device:R | Resistor_SMD:R_0805_2012Metric | ~
 |  | R14 | 1.5k | Device:R | Resistor_SMD:R_0805_2012Metric | ~
 |  | R15 | 3.9k | Device:R | Resistor_SMD:R_0805_2012Metric | ~
 |  | R16 | 10K | Device:R | Resistor_SMD:R_0805_2012Metric | ~
 |  | R17 | 10K | Device:R | Resistor_SMD:R_0805_2012Metric | ~
 |  | R18 | 22.1K | Device:R | Resistor_SMD:R_0805_2012Metric | ~
 |  | R19 | 47.5K | Device:R | Resistor_SMD:R_0805_2012Metric | ~
 |  | R20 | 10K | Device:R | Resistor_SMD:R_0805_2012Metric | ~
 |  | R21 | 1K | Device:R | Resistor_SMD:R_0805_2012Metric | ~
 |  | R22 | 10K | Device:R | Resistor_SMD:R_0805_2012Metric | ~
 |  | R23 | 10K | Device:R | Resistor_SMD:R_0805_2012Metric | ~
 |  | U1 | PAM2421AECADJR | PAM2421AECADJR:PAM2421AECADJR | Kicad:SOIC127P600X175-8N |  |  |  |  | Diodes Inc. |  | SOIC127P600X175-8N
 |  | U2 | L6981C33DR | 2023-02-22_21-42-58:L6981C33DR | footprints2.0:L6981C33DR
 |  | U3 | INA219AxD | Sensor_Energy:INA219AxD | Package_SO:SOIC-8_3.9x4.9mm_P1.27mm | http://www.ti.com/lit/ds/symlink/ina219.pdf
 |  | U4 | FAN32SV10MMPX | homeMade:FAN32SV10MMPX | footprints1.0:FAN23SV10M
 |  | U5 | INA219AxD | Sensor_Energy:INA219AxD | Package_SO:SOIC-8_3.9x4.9mm_P1.27mm | http://www.ti.com/lit/ds/symlink/ina219.pdf
 |  | U6 | MCP4531-103E/MS | MCP4531-103E_MS:MCP4531-103E{slash}MS | Kicad:SOP65P490X110-8N
 |  | U7 | CP2102N-Axx-xQFN28 | Interface_USB:CP2102N-Axx-xQFN28 | Package_DFN_QFN:QFN-28-1EP_5x5mm_P0.5mm_EP3.35x3.35mm | https://www.silabs.com/documents/public/data-sheets/cp2102n-datasheet.pdf
 |  | U8 | ESP32-S3-WROOM-2-N32R8V | ESP32-S3-WROOM-2-N32R8V:ESP32-S3-WROOM-2-N32R8V | Kicad:XCVR_ESP32-S3-WROOM-2-N32R8V |  | Espressif | 3.25mm |  |  | 1.0 |  | ESP32-S3-WROOM-2-N32R8V | Manufacturer Recommendations
 |  | U9 | PTS645SM43SMTR92LFS | 2023-03-02_01-59-27:PTS645SM43SMTR92LFS | SWITCH_43SMTR92LFS
 |  | U10 | PTS645SM43SMTR92LFS | 2023-03-02_01-59-27:PTS645SM43SMTR92LFS | SWITCH_43SMTR92LFS
Collated Components:
Item | Qty | Reference(s) | Value | LibPart | Footprint | Datasheet | MANUFACTURER | MAXIMUM_PACKAGE_HEIGHT | MF | Manufacturer | PARTREV | Package | SNAPEDA_PN | STANDARD
1 | 2 | C1, C11 | 470μF | Device:C | Capacitor_THT:CP_Radial_D13.0mm_P5.00mm | ~
2 | 1 | C2 | 2.2pF | Device:C | Capacitor_SMD:C_0805_2012Metric | ~
3 | 4 | C3, C4, C10, C24 | 10μF | Device:C | Capacitor_SMD:C_0805_2012Metric | ~
4 | 1 | C5 | 47pF | Device:C | Capacitor_SMD:C_0805_2012Metric | ~
5 | 5 | C6, C7, C13, C17, C23 | 1μF | Device:C | Capacitor_SMD:C_0805_2012Metric | ~
6 | 1 | C8 | 10nF | Device:C | Capacitor_SMD:C_0805_2012Metric | ~
7 | 1 | C9 | 100nF | Device:C | Capacitor_SMD:C_0805_2012Metric | ~
8 | 2 | C12, C22 | 22μF | Device:C | Capacitor_SMD:C_0805_2012Metric | ~
9 | 1 | C14 | 15nF | Device:C | Capacitor_SMD:C_0805_2012Metric | ~
10 | 5 | C15, C19, C21, C25, C26 | 0.1μF | Device:C | Capacitor_SMD:C_0805_2012Metric | ~
11 | 1 | C16 | 2.2μF | Device:C | Capacitor_SMD:C_0805_2012Metric | ~
12 | 1 | C18 | 33μF | Device:C | Capacitor_SMD:C_1206_3216Metric | ~
13 | 1 | C20 | 100pF | Device:C | Capacitor_SMD:C_0805_2012Metric | ~
14 | 1 | CR1 | SS34-E3/57T | 2023-02-22_21-35-58:SS34-E3{slash}57T | footprints1.0:SS34-E3&slash_57T
15 | 3 | D1, D2, D3 | PESD5V0L1BA,115 | Diode:ESD9B5.0ST5G | Diode_SMD:D_SOD-323 | https://www.onsemi.com/pub/Collateral/ESD9B-D.PDF
16 | 3 | J1, J2, J4 | Screw_Terminal_01x02 | Connector:Screw_Terminal_01x02 | footprints3.0:YO0221500000G | ~
17 | 1 | J3 | Conn_01x02_Male | Connector:Conn_01x02_Male | Connector_PinHeader_2.54mm:PinHeader_1x02_P2.54mm_Vertical | ~
18 | 1 | J5 | ZX62D-B-5P8 | ZX62D-B-5P8:ZX62D-B-5P8 | Kicad:HRS_ZX62D-B-5P8 |  |  |  | Hirose Electric |  | N/A |  |  | Manufacturer Recommendations
19 | 1 | L1 | 6.8μH | Device:L | Inductor_THT:L_Toroid_Vertical_L26.7mm_W14.0mm_P10.16mm_Pulse_D | ~
20 | 1 | L2 | 33μH | Device:L | Inductor_SMD:L_Bourns_SRN6045TA | ~
21 | 1 | L3 | 49μH | Device:L | Inductor_THT:L_Toroid_Vertical_L21.6mm_W9.1mm_P8.40mm_Bourns_5700 | ~
22 | 1 | Q1 | IRLZ34N | Transistor_FET:IRLZ34N | Package_TO_SOT_THT:TO-220-3_Vertical | http://www.infineon.com/dgdl/irlz34npbf.pdf?fileId=5546d462533600a40153567206892720
23 | 1 | Q2 | FQP27P06 | Transistor_FET:FQP27P06 | Package_TO_SOT_THT:TO-220-3_Vertical | https://www.onsemi.com/pub/Collateral/FQP27P06-D.PDF
24 | 2 | Q3, Q4 | BC818 | Transistor_BJT:BC818 | Package_TO_SOT_SMD:SOT-23 | https://www.onsemi.com/pub/Collateral/BC818-D.pdf
25 | 1 | R1 | 51k | Device:R | Resistor_SMD:R_0805_2012Metric | ~
26 | 1 | R2 | 47k | Device:R | Resistor_SMD:R_0805_2012Metric | ~
27 | 1 | R3 | 18k | Device:R | Resistor_SMD:R_0805_2012Metric | ~
28 | 1 | R4 | 82k | Device:R | Resistor_SMD:R_0805_2012Metric | ~
29 | 1 | R5 | 9.1k | Device:R | Resistor_SMD:R_0805_2012Metric | ~
30 | 2 | R6, R10 | R_Shunt | Device:R_Shunt | Package_TO_SOT_THT:TO-220-2_Vertical | ~
31 | 5 | R7, R8, R11, R12, R13 | 10 | Device:R | Resistor_SMD:R_0805_2012Metric | ~
32 | 1 | R9 | 150k | Device:R | Resistor_SMD:R_0805_2012Metric | ~
33 | 1 | R14 | 1.5k | Device:R | Resistor_SMD:R_0805_2012Metric | ~
34 | 1 | R15 | 3.9k | Device:R | Resistor_SMD:R_0805_2012Metric | ~
35 | 5 | R16, R17, R20, R22, R23 | 10K | Device:R | Resistor_SMD:R_0805_2012Metric | ~
36 | 1 | R18 | 22.1K | Device:R | Resistor_SMD:R_0805_2012Metric | ~
37 | 1 | R19 | 47.5K | Device:R | Resistor_SMD:R_0805_2012Metric | ~
38 | 1 | R21 | 1K | Device:R | Resistor_SMD:R_0805_2012Metric | ~
39 | 1 | U1 | PAM2421AECADJR | PAM2421AECADJR:PAM2421AECADJR | Kicad:SOIC127P600X175-8N |  |  |  |  | Diodes Inc. |  | SOIC127P600X175-8N
40 | 1 | U2 | L6981C33DR | 2023-02-22_21-42-58:L6981C33DR | footprints2.0:L6981C33DR
41 | 2 | U3, U5 | INA219AxD | Sensor_Energy:INA219AxD | Package_SO:SOIC-8_3.9x4.9mm_P1.27mm | http://www.ti.com/lit/ds/symlink/ina219.pdf
42 | 1 | U4 | FAN32SV10MMPX | homeMade:FAN32SV10MMPX | footprints1.0:FAN23SV10M
43 | 1 | U6 | MCP4531-103E/MS | MCP4531-103E_MS:MCP4531-103E{slash}MS | Kicad:SOP65P490X110-8N
44 | 1 | U7 | CP2102N-Axx-xQFN28 | Interface_USB:CP2102N-Axx-xQFN28 | Package_DFN_QFN:QFN-28-1EP_5x5mm_P0.5mm_EP3.35x3.35mm | https://www.silabs.com/documents/public/data-sheets/cp2102n-datasheet.pdf
45 | 1 | U8 | ESP32-S3-WROOM-2-N32R8V | ESP32-S3-WROOM-2-N32R8V:ESP32-S3-WROOM-2-N32R8V | Kicad:XCVR_ESP32-S3-WROOM-2-N32R8V |  | Espressif | 3.25mm |  |  | 1.0 |  | ESP32-S3-WROOM-2-N32R8V | Manufacturer Recommendations
46 | 2 | U9, U10 | PTS645SM43SMTR92LFS | 2023-03-02_01-59-27:PTS645SM43SMTR92LFS | SWITCH_43SMTR92LFS

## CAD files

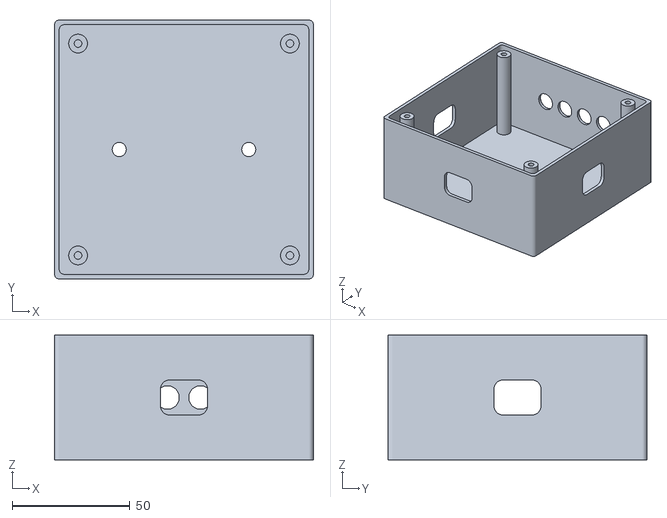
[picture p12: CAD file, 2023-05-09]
case/stl/Base.stl
110.0 x 110.0 x 53.0

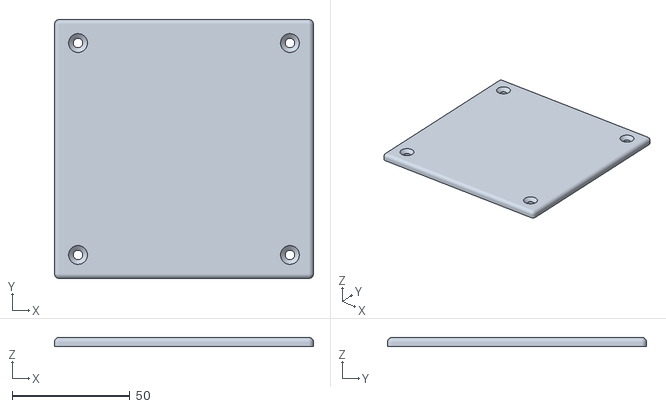
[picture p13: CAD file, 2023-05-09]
case/stl/Lid.stl
110.0 x 110.0 x 4.00

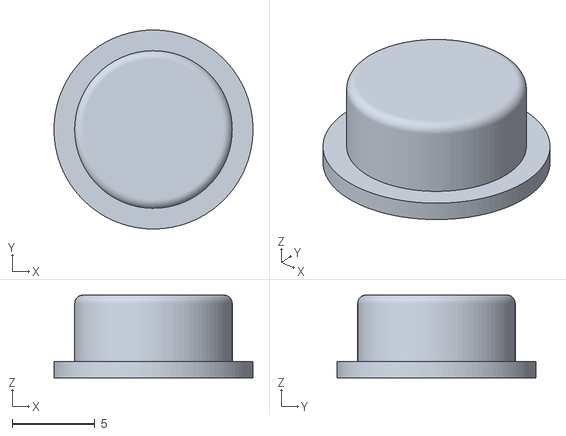
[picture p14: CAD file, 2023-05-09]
case/stl/Button.stl
12.0 x 12.0 x 5.00

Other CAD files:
case/inventor/Base.ipt
case/inventor/Button.ipt
case/inventor/Lid.ipt
case/inventor/OldVersions/Base.0016.ipt
case/inventor/OldVersions/Button.0001.ipt
case/inventor/OldVersions/Lid.0008.ipt
case/inventor/OldVersions/PCB.0001.ipt
case/inventor/OldVersions/case.0005.iam
case/inventor/PCB.ipt
case/inventor/case.iam

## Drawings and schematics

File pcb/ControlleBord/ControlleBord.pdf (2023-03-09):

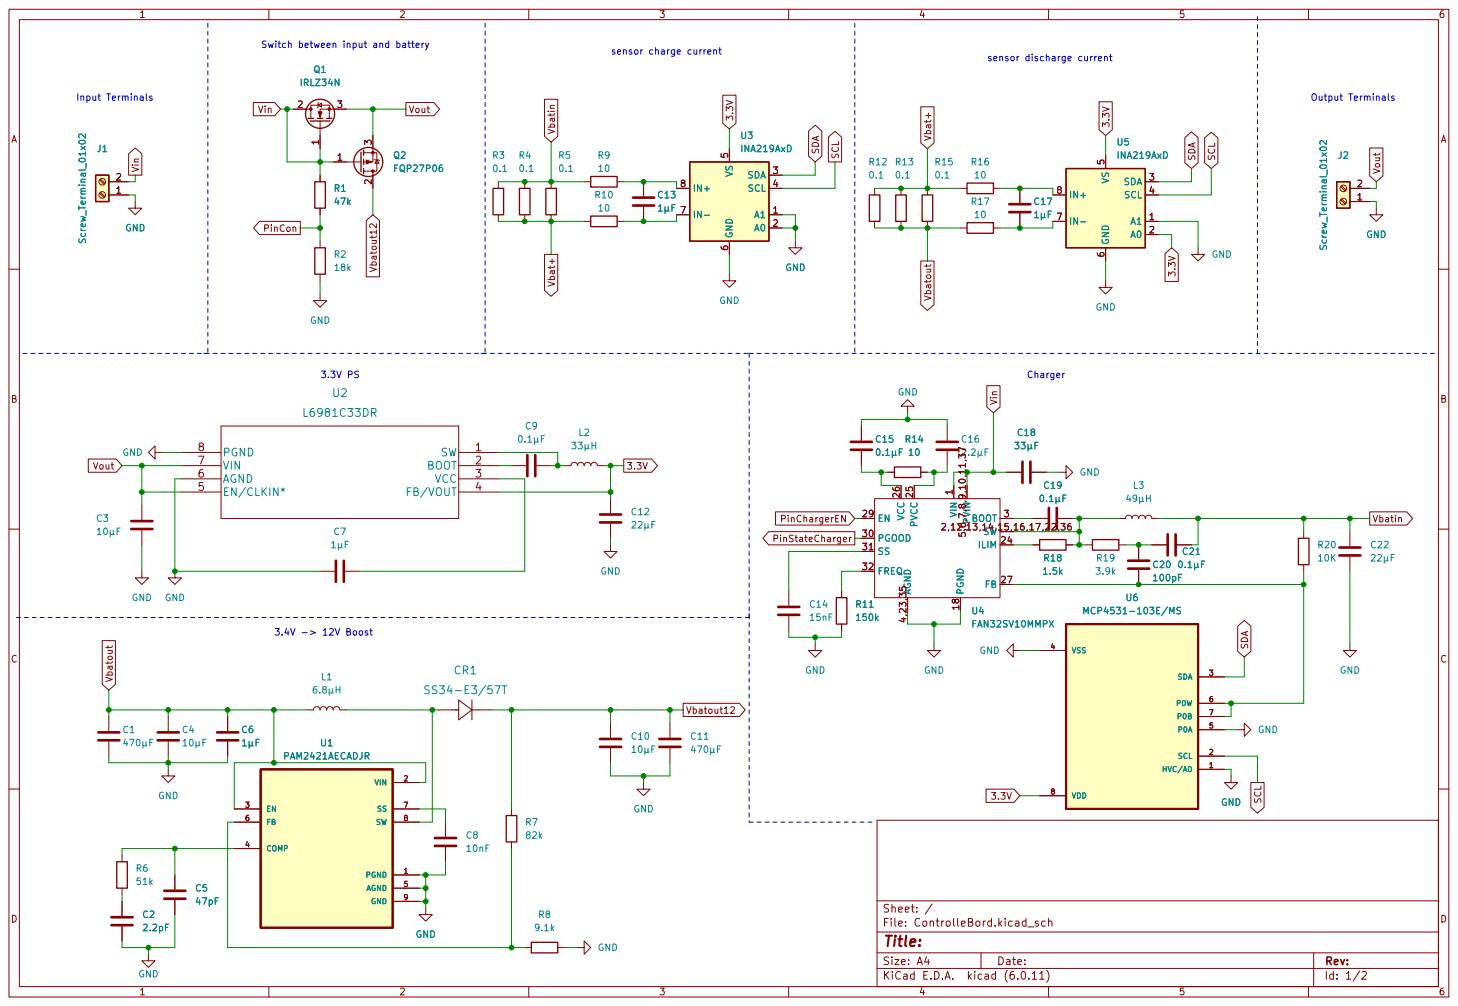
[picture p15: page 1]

Id: 1/2 Title: File: ControlleBord.kicad_sch Sheet: /

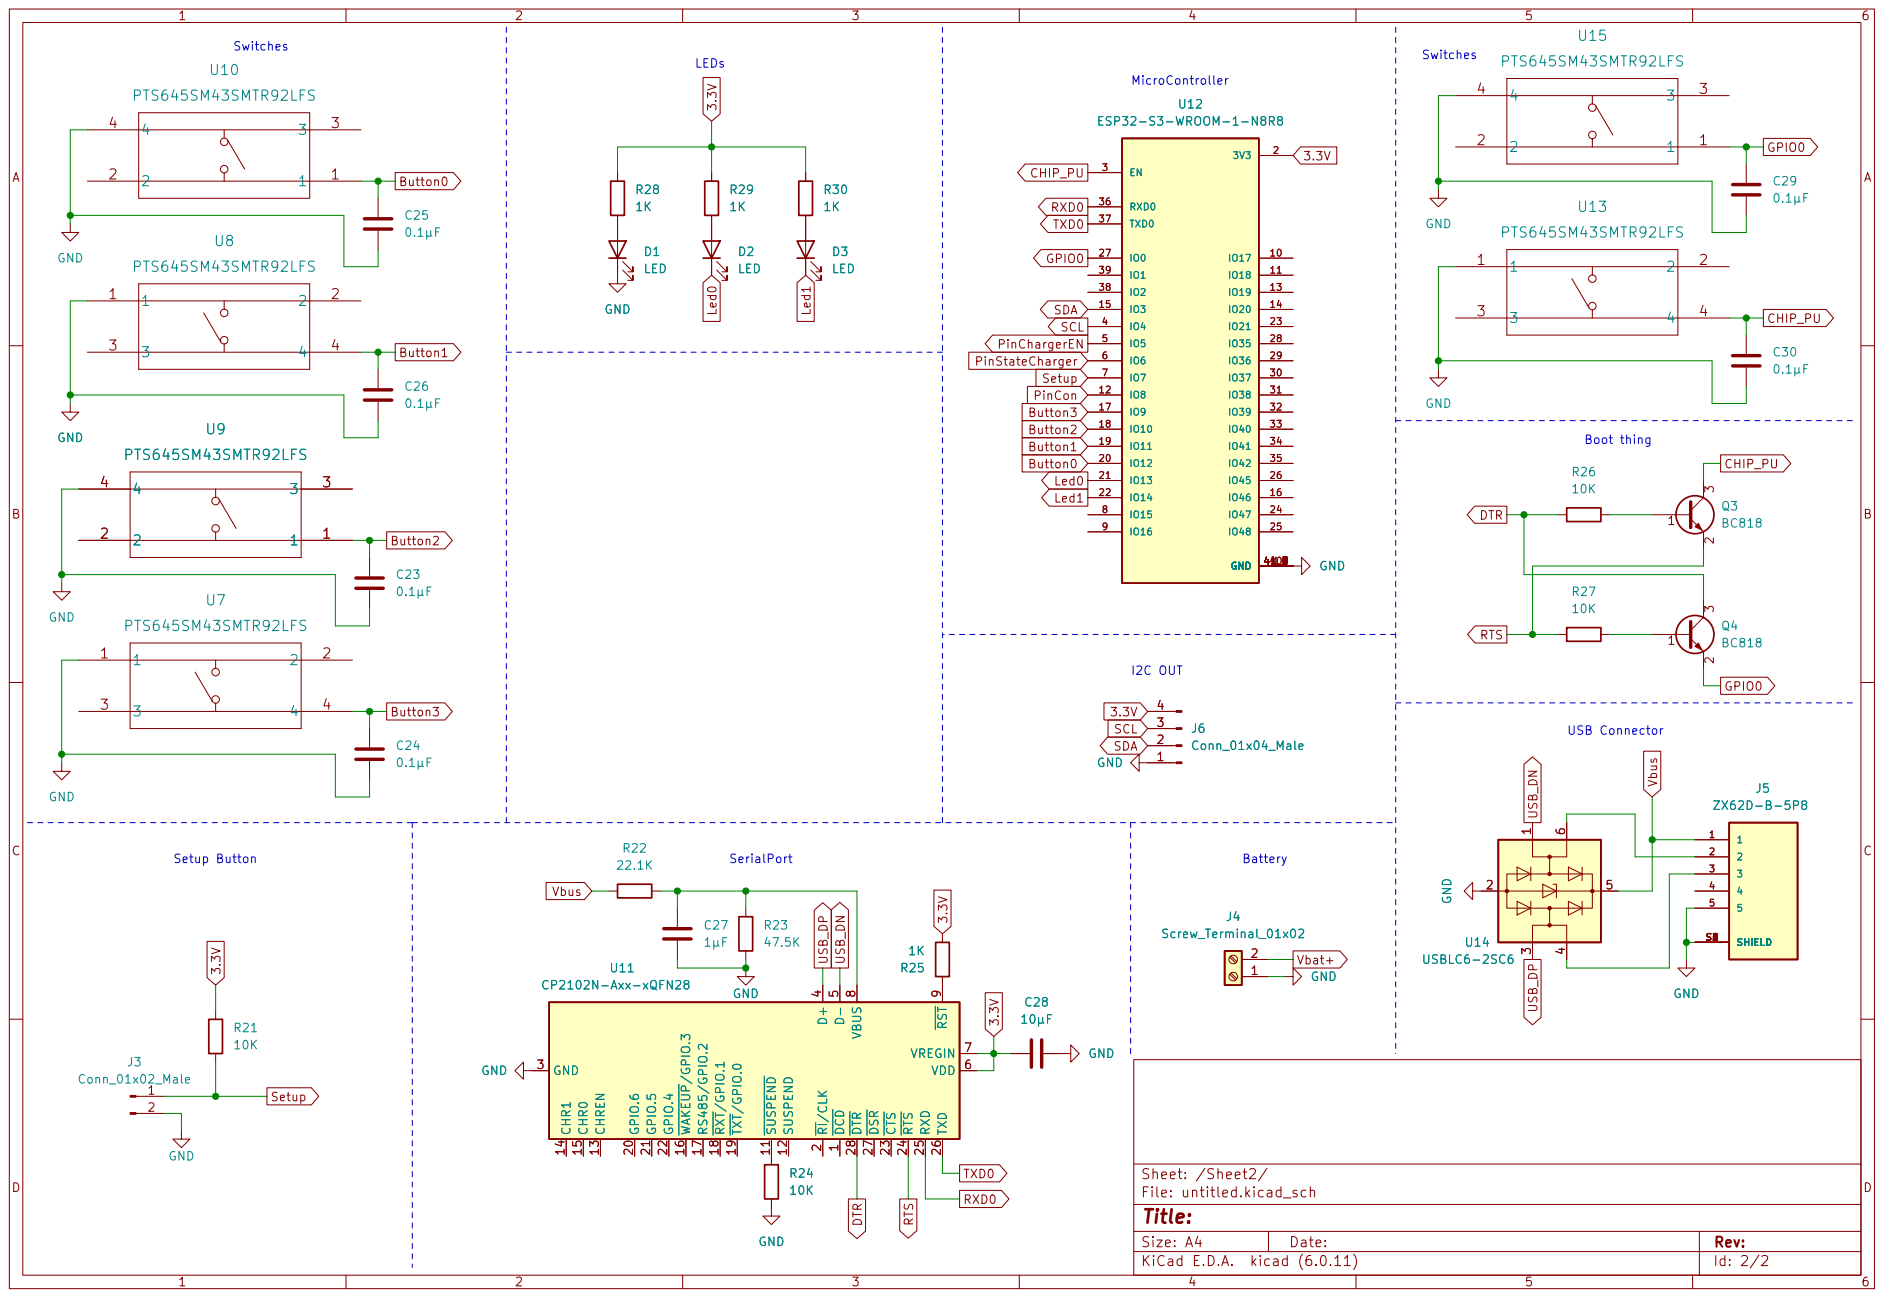
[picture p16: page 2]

2 GPIO.6 20 GPIO.5 21 GPIO.4 22 ~{CTS} 23 ~{RTS} 24 RXD 25 TXD 26 ~{DSR} 27 ~{DTR} 28 GND 3 D+

Id: 2/2 Title: File: untitled.kicad_sch Sheet: /Sheet2/

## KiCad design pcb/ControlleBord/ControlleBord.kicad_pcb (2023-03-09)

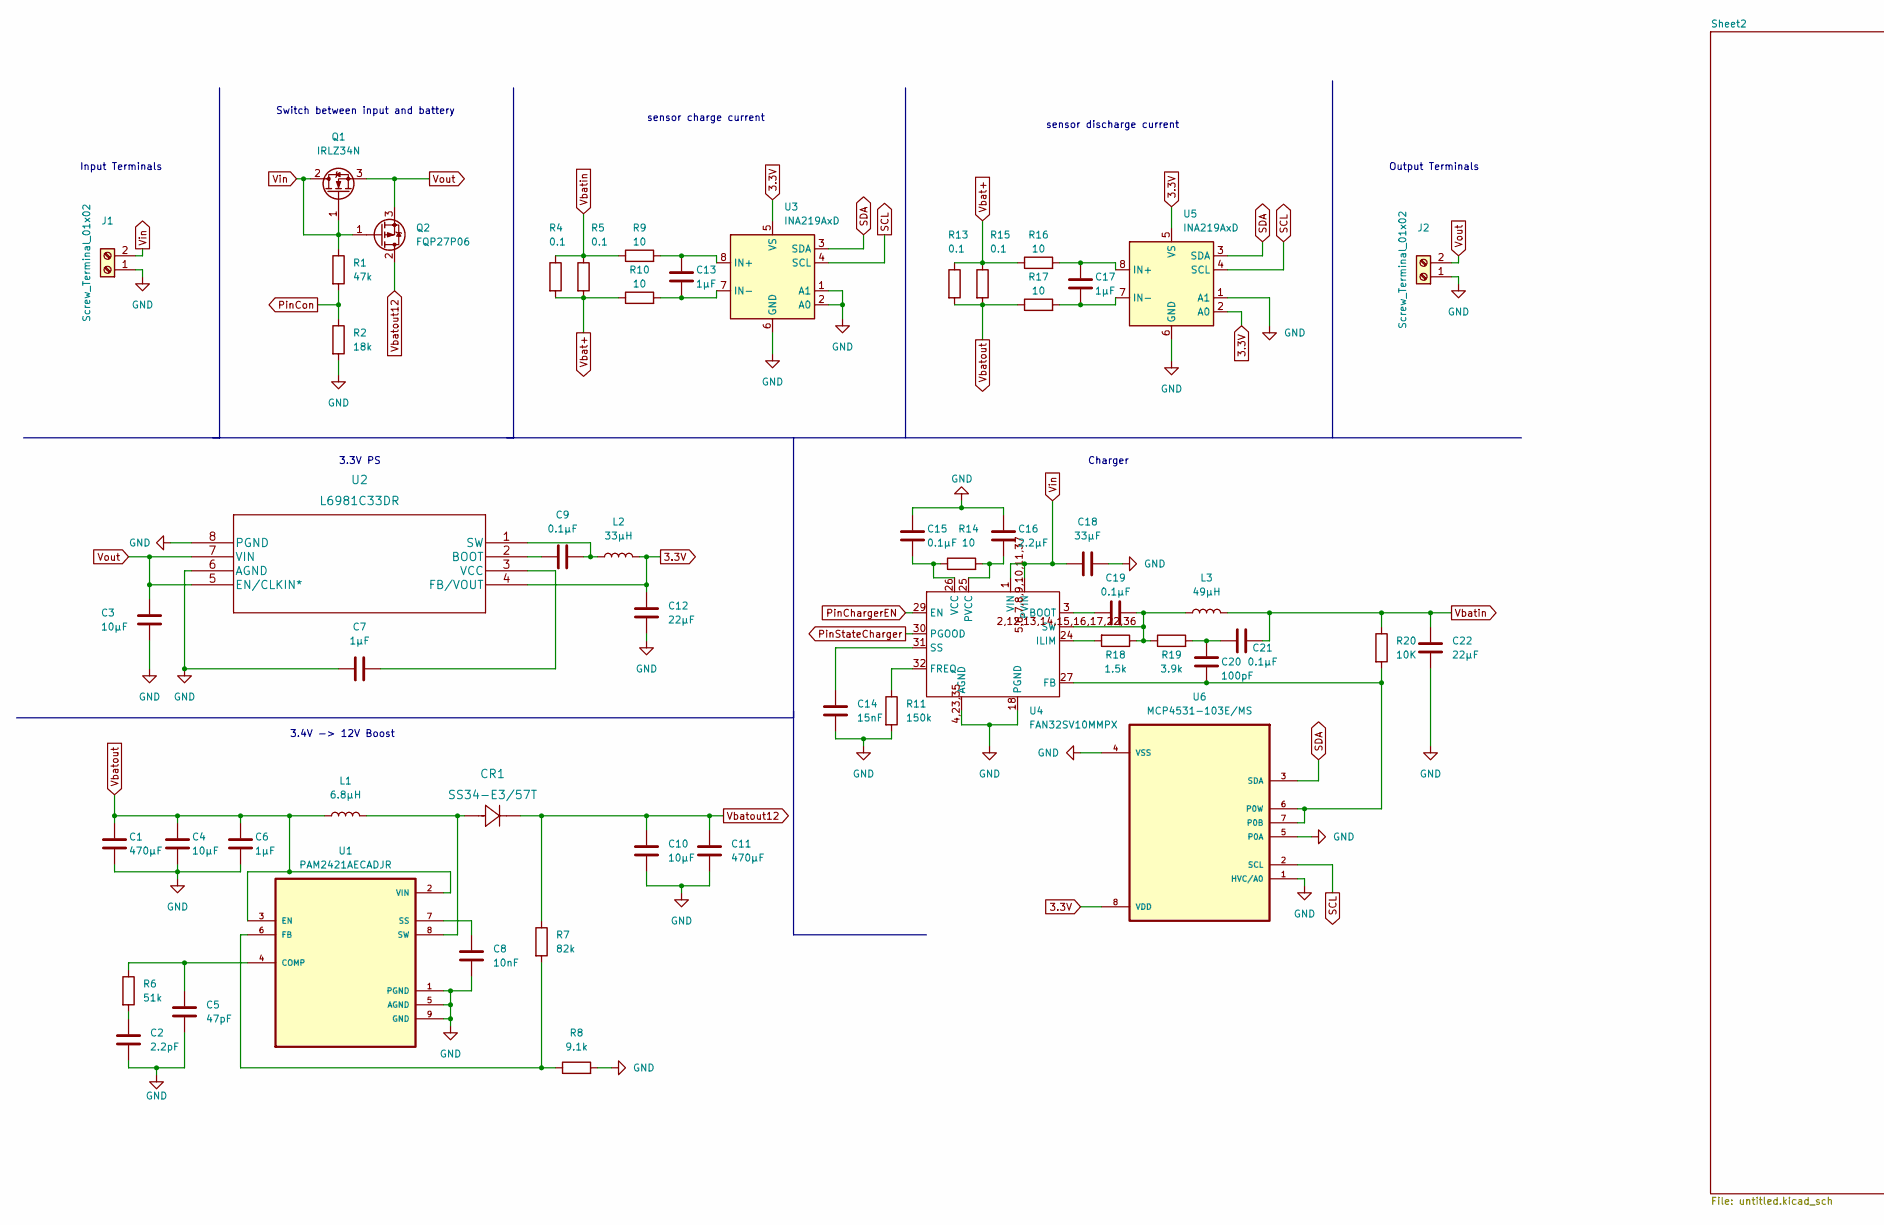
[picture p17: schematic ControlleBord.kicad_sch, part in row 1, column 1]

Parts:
C1, C11: 470μF; CP_Radial_D13.0mm_P5.00mm
C2: 2.2pF; C_0805_2012Metric
C3, C4, C10: 10μF; C_0805_2012Metric
C5: 47pF; C_0805_2012Metric
C6, C7, C13, C17: 1μF; C_0805_2012Metric
C8: 10nF; C_0805_2012Metric
C9, C15, C19, C21: 0.1μF; C_0805_2012Metric
C12, C22: 22μF; C_0805_2012Metric
C14: 15nF; C_0805_2012Metric
C16: 2.2μF; C_0805_2012Metric
C18: 33μF; C_1206_3216Metric
C20: 100pF; C_0805_2012Metric
CR1: SS34-E3/57T; SS34-E3&slash_57T
J1, J2: Screw_Terminal_01x02; YO0221500000G
L1: 6.8μH; L_Toroid_Vertical_L26.7mm_W14.0mm_P10.16mm_Pulse_D
L2: 33μH; L_Bourns_SRN6045TA
L3: 49μH; L_Toroid_Vertical_L21.6mm_W9.1mm_P8.40mm_Bourns_5700
Q1: IRLZ34N; TO-220-3_Vertical
Q2: FQP27P06; TO-220-3_Vertical
R1: 47k; R_0805_2012Metric
R2: 18k; R_0805_2012Metric
R4, R5, R13, R15: 0.1; R_2512_6332Metric
R6: 51k; R_0805_2012Metric
R7: 82k; R_0805_2012Metric
R8: 9.1k; R_0805_2012Metric
R9, R10, R14, R16, R17: 10; R_0805_2012Metric
R11: 150k; R_0805_2012Metric
R18: 1.5k; R_0805_2012Metric
R19: 3.9k; R_0805_2012Metric
R20: 10K; R_0805_2012Metric
U1: PAM2421AECADJR; SOIC127P600X175-8N
U2: L6981C33DR
U3, U5: INA219AxD; SOIC-8_3.9x4.9mm_P1.27mm
U4: FAN32SV10MMPX; FAN23SV10M
U6: MCP4531-103E/MS; SOP65P490X110-8N

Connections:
3.3V: C12.1, L2.2, U2.4 (FB/VOUT), U3.5 (VS), U5.2 (A0), U5.5 (VS), U6.8 (VDD); also elsewhere on the board
GND: C1.2, C2.2, C3.2, C4.2, C5.2, C6.2, C7.1, C8.2, C10.2, C11.2, C12.2, C14.2, C15.1, C16.1, C18.2, C22.2, J1.1, J2.1, R2.2, R8.2, R11.2, U1.1 (PGND), U1.5 (AGND), U1.9 (GND), U2.6 (AGND), U2.8 (PGND), U3.1 (A1), U3.2 (A0), U3.6 (GND), U4.4,23,35 (AGND), U4.18 (PGND), U5.1 (A1), U5.6 (GND), U6.1 (HVC/A0), U6.4 (VSS), U6.5 (P0A); also elsewhere on the board
unnamed: C2.1, R6.2
unnamed: C5.1, R6.1, U1.4 (COMP)
unnamed: C7.2, U2.3 (VCC)
unnamed: C8.1, U1.7 (SS)
unnamed: C9.1, U2.2 (BOOT)
unnamed: C9.2, L2.1, U2.1 (SW)
unnamed: C13.1, R9.2, U3.8 (IN+)
unnamed: C13.2, R10.2, U3.7 (IN-)
unnamed: C14.1, U4.31 (SS)
unnamed: C15.2, R14.1, U4.26 (VCC)
unnamed: C16.2, R14.2, U4.25 (PVCC)
unnamed: C17.1, R16.2, U5.8 (IN+)
unnamed: C17.2, R17.2, U5.7 (IN-)
unnamed: C19.1, U4.3 (BOOT)
unnamed: C19.2, L3.1, R18.1, R19.1, U4.2,12,13,14,15,16,17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 (SW)
unnamed: C20.1, C21.1, R19.2
unnamed: C20.2, R20.2, U4.27 (FB), U6.6 (P0W), U6.7 (P0B)
unnamed: CR1.2, L1.2, U1.8 (SW)
unnamed: R7.2, R8.1, U1.6 (FB)
unnamed: R11.1, U4.32 (FREQ)
unnamed: R18.2, U4.24 (ILIM)
PinChargerEN: U4.29 (EN); also elsewhere on the board
PinCon: R1.2, R2.1; also elsewhere on the board
PinStateCharger: U4.30 (PGOOD); also elsewhere on the board
SCL: U3.4 (SCL), U5.4 (SCL), U6.2 (SCL); also elsewhere on the board
SDA: U3.3 (SDA), U5.3 (SDA), U6.3 (SDA); also elsewhere on the board
Vbat+: R4.2, R5.2, R10.1, R13.1, R15.1, R16.1; also elsewhere on the board
Vbatin: C21.2, C22.1, L3.2, R4.1, R5.1, R9.1, R20.1
Vbatout: C1.1, C4.1, C6.1, L1.1, R13.2, R15.2, R17.1, U1.2 (VIN), U1.3 (EN); also elsewhere on the board
Vbatout12: C10.1, C11.1, CR1.1, Q2.2 (D), R7.1; also elsewhere on the board
Vin: C18.1, J1.2, Q1.1 (G), Q1.2 (D), Q2.1 (G), R1.1, U4.1 (VIN), U4.5,6,7,8,9,10,11,37 (PVIN)
Vout: C3.1, J2.2, Q1.3 (S), Q2.3 (S), U2.5 (EN/CLKIN*), U2.7 (VIN)

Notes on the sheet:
Charger
Input Terminals
Switch between input and battery
sensor charge current
sensor discharge current
Output Terminals
3.3V PS
3.4V -> 12V Boost

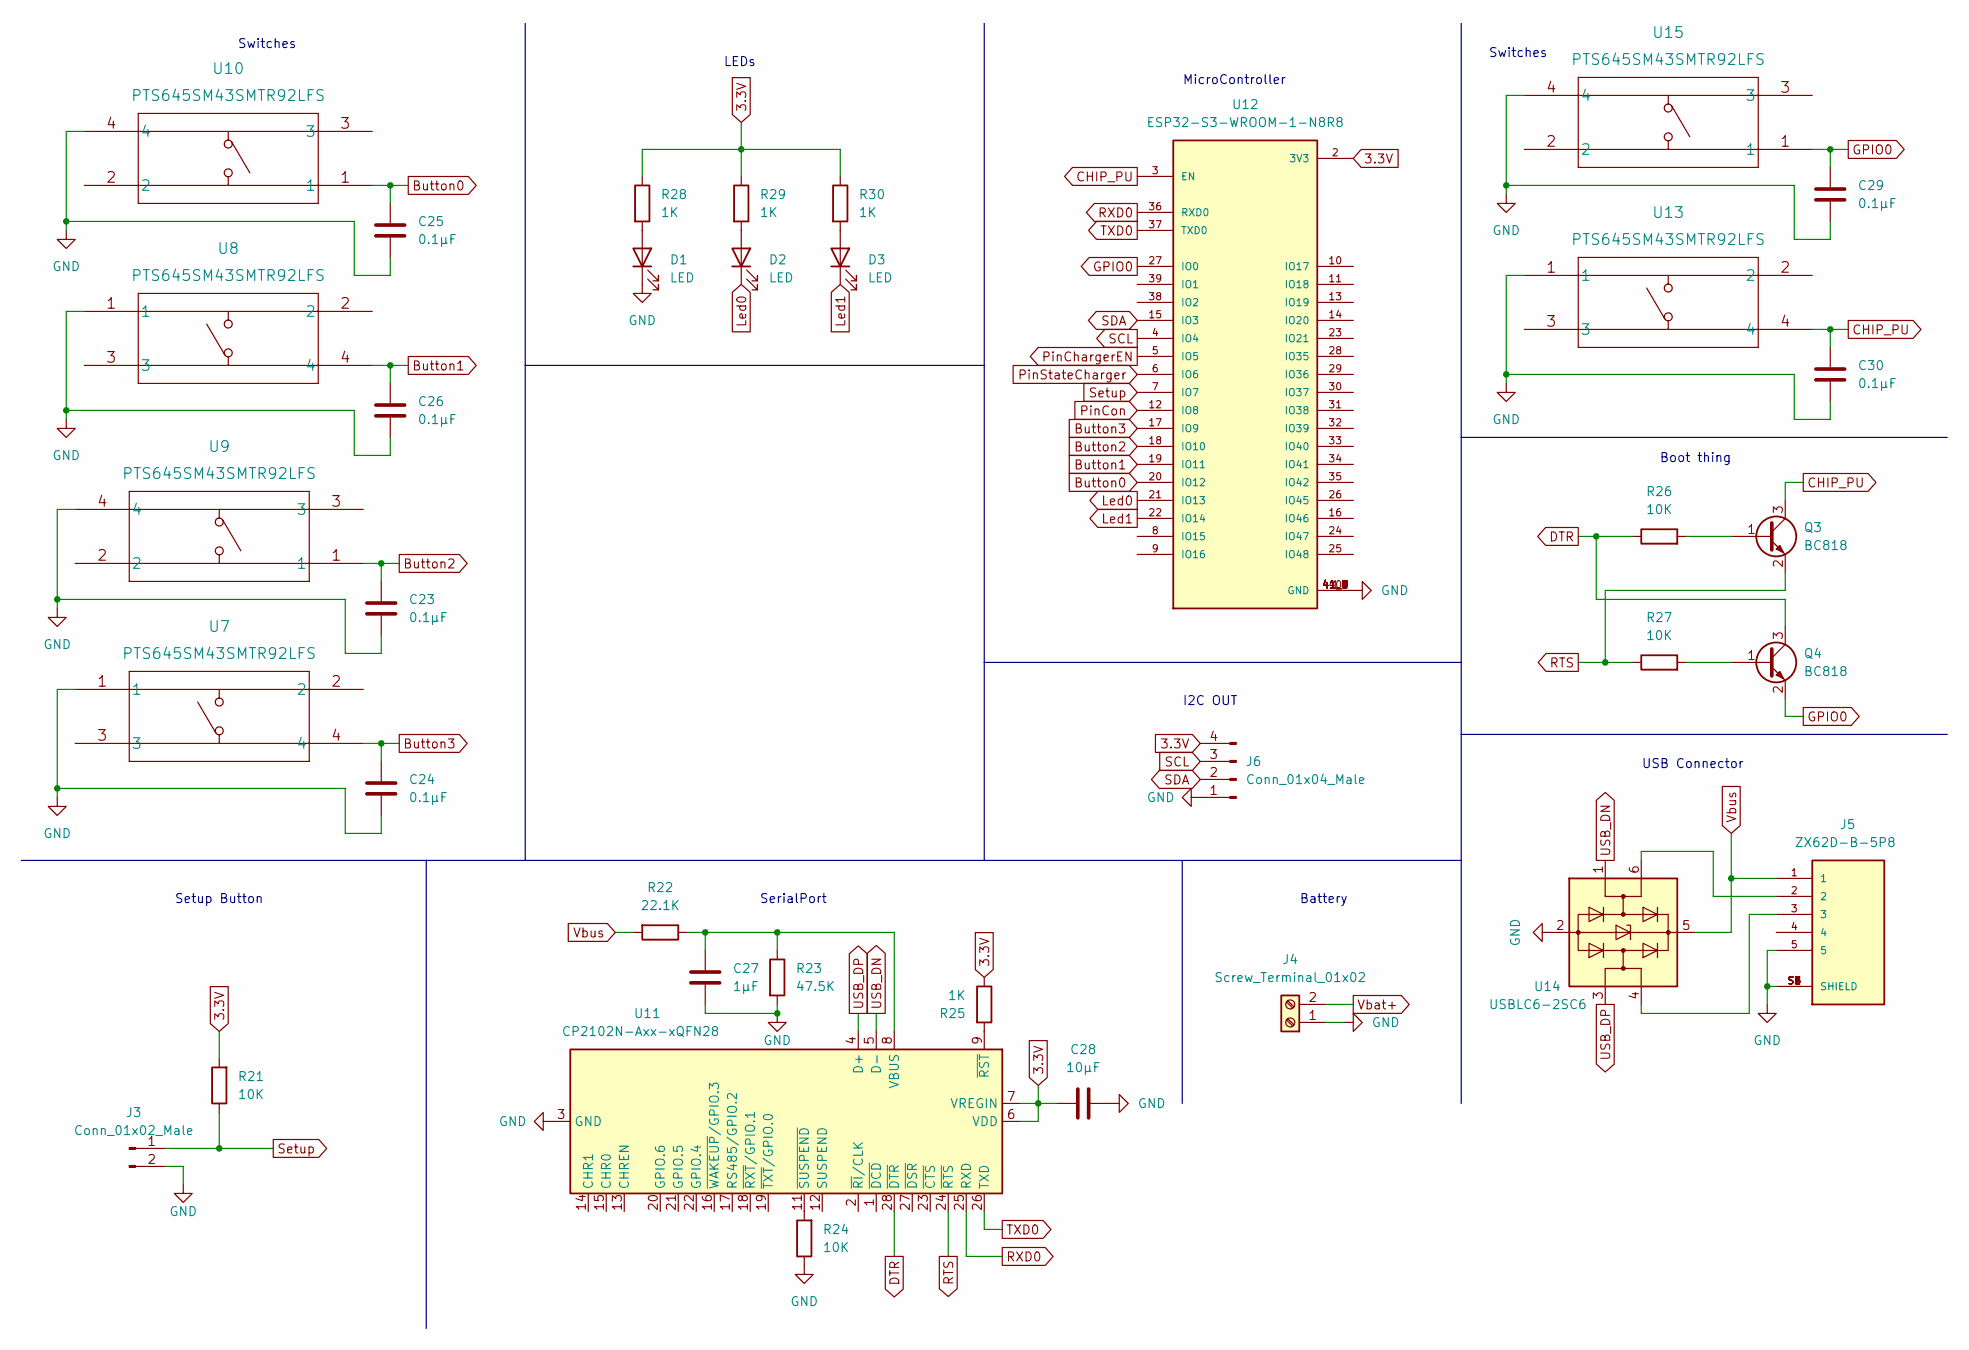
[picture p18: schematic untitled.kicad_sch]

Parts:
C23, C24, C25, C26, C29, C30: 0.1μF; C_0805_2012Metric
C27: 1μF; C_0805_2012Metric
C28: 10μF; C_0805_2012Metric
D1, D2, D3: LED; R_0805_2012Metric
J3: Conn_01x02_Male; PinHeader_1x02_P2.54mm_Vertical
J4: Screw_Terminal_01x02; YO0221500000G
J5: ZX62D-B-5P8; HRS_ZX62D-B-5P8; PARTREV N/A
J6: Conn_01x04_Male; PinSocket_1x04_P2.54mm_Vertical
Q3, Q4: BC818; SOT-23
R21, R24, R26, R27: 10K; R_0805_2012Metric
R22: 22.1K; R_0805_2012Metric
R23: 47.5K; R_0805_2012Metric
R25, R28, R29, R30: 1K; R_0805_2012Metric
U7, U8, U9, U10, U13, U15: PTS645SM43SMTR92LFS
U11: CP2102N-Axx-xQFN28; QFN-28-1EP_5x5mm_P0.5mm_EP3.35x3.35mm
U12: ESP32-S3-WROOM-1-N8R8; XCVR_ESP32S3WROOM1N8R8
U14: USBLC6-2SC6; SOT-23-6

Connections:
3.3V: C28.1, J6.4, R21.2, R25.1, R28.1, R29.1, R30.1, U11.6 (VDD), U11.7 (VREGIN), U12.2 (3V3); also elsewhere on the board
Button0: C25.2, U10.1, U12.20 (IO12)
Button1: C26.1, U8.4, U12.19 (IO11)
Button2: C23.2, U9.1, U12.18 (IO10)
Button3: C24.1, U7.4, U12.17 (IO9)
CHIP_PU: C30.1, Q3.3 (C), U12.3 (EN), U13.4
DTR: Q4.3 (C), R26.1, U11.28 (~DTR)
GND: C23.1, C24.2, C25.1, C26.2, C27.2, C28.2, C29.1, C30.2, D1.1 (K), J3.2, J4.1, J5.5, J5.S1 (SHIELD), J5.S2 (SHIELD), J5.S3 (SHIELD), J5.S4 (SHIELD), J5.S5 (SHIELD), J5.S6 (SHIELD), J6.1, R23.2, R24.1, U7.1, U8.1, U9.4, U10.4, U11.3 (GND), U11.29 (GND), U12.1 (GND), U12.40 (GND), U12.41_1 (GND), U12.41_2 (GND), U12.41_3 (GND), U12.41_4 (GND), U12.41_5 (GND), U12.41_6 (GND), U12.41_7 (GND), U12.41_8 (GND), U12.41_9 (GND), U13.1, U14.2 (GND), U15.4; also elsewhere on the board
GPIO0: C29.2, Q4.2 (E), U12.27 (IO0), U15.1
Led0: D2.1 (K), U12.21 (IO13)
Led1: D3.1 (K), U12.22 (IO14)
unnamed: C27.1, R22.1, R23.1, U11.8 (VBUS)
unnamed: D1.2 (A), R28.2
unnamed: D2.2 (A), R29.2
unnamed: D3.2 (A), R30.2
unnamed: J5.2, U14.6 (I/O1)
unnamed: J5.3, U14.4 (I/O2)
unnamed: Q3.1 (B), R26.2
unnamed: Q4.1 (B), R27.2
unnamed: R24.2, U11.11 (~SUSPEND)
unnamed: R25.2, U11.9 (~RST)
PinChargerEN: U12.5 (IO5); also elsewhere on the board
PinCon: U12.12 (IO8); also elsewhere on the board
PinStateCharger: U12.6 (IO6); also elsewhere on the board
RTS: Q3.2 (E), R27.1, U11.24 (~RTS)
RXD0: U11.25 (RXD), U12.36 (RXD0)
SCL: J6.3, U12.4 (IO4); also elsewhere on the board
SDA: J6.2, U12.15 (IO3); also elsewhere on the board
Setup: J3.1, R21.1, U12.7 (IO7)
TXD0: U11.26 (TXD), U12.37 (TXD0)
USB_DN: U11.5 (D-), U14.1 (I/O1)
USB_DP: U11.4 (D+), U14.3 (I/O2)
Vbat+: J4.2; also elsewhere on the board
Vbus: J5.1, R22.2, U14.5 (VBUS)

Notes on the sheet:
SerialPort
USB Connector
Setup Button
Switches
MicroController
LEDs
Battery
I2C OUT
Boot thing

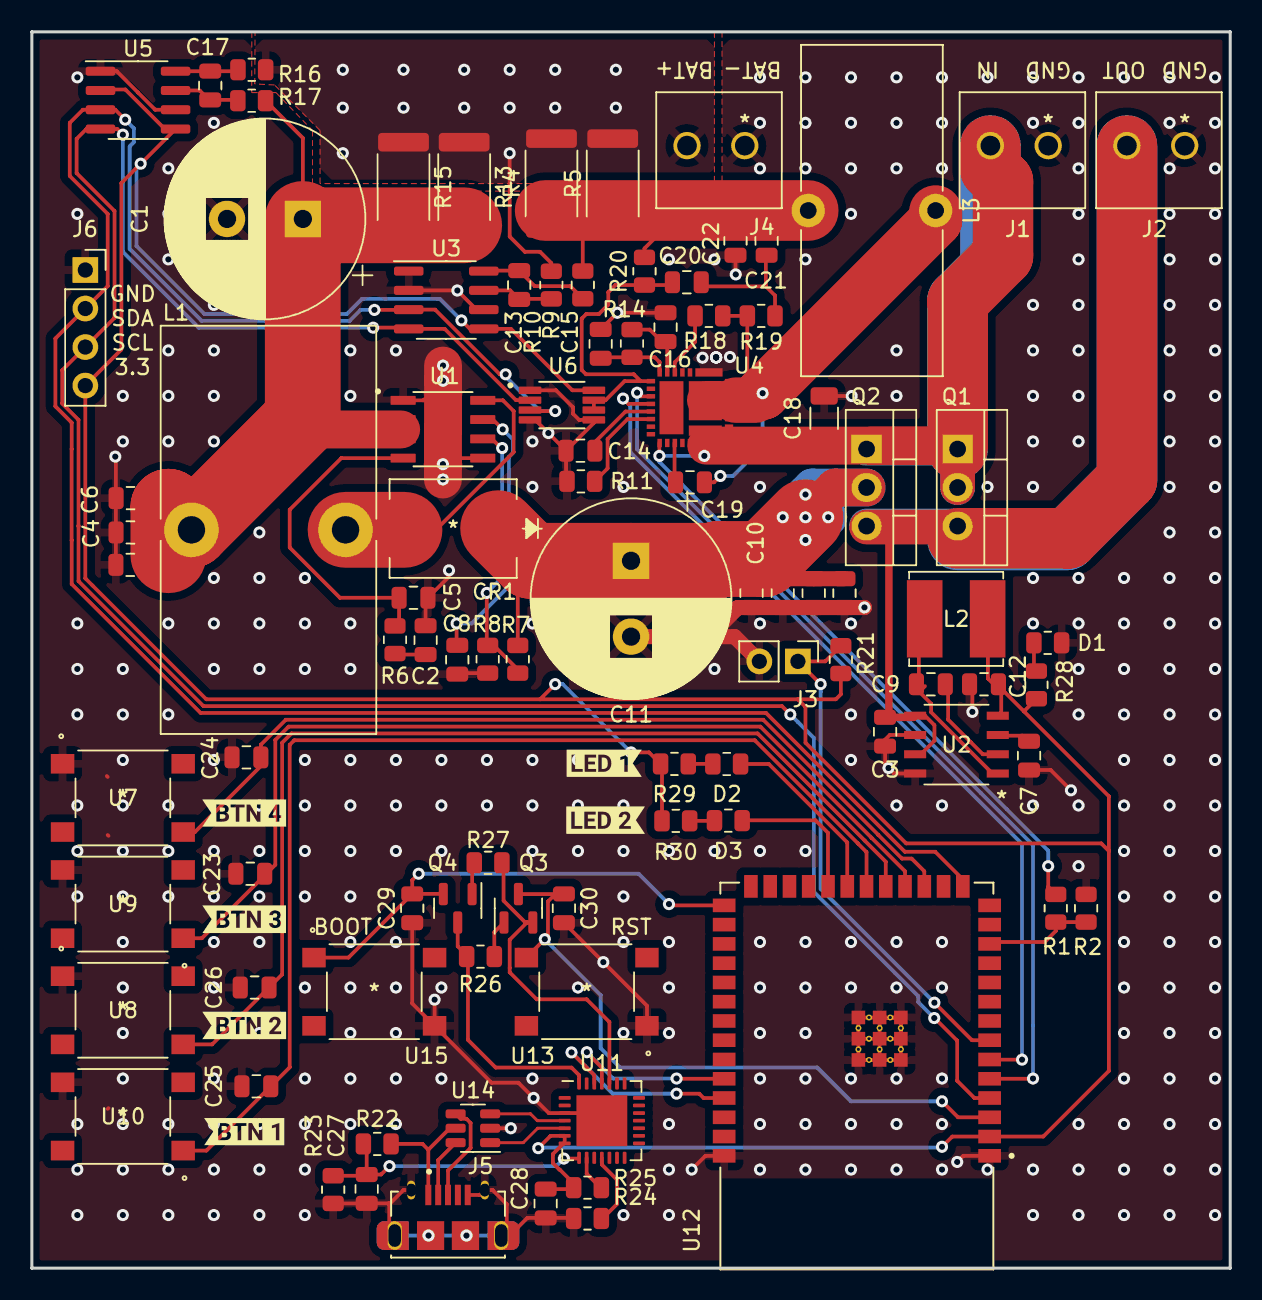
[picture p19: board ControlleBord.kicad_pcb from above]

Board: 2 copper layers, 79.0 x 81.5 mm, 100 parts (0 on the bottom side), 60 nets.

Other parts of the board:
C4#2, C10#2, C10#3, C10#4: 10μF; C_0805_2012Metric
kibuzzard-6409D4B5: G***; kibuzzard-6409D4B5
kibuzzard-6409D4BC: G***; kibuzzard-6409D4BC
kibuzzard-6409D4C2: G***; kibuzzard-6409D4C2
kibuzzard-6409D4D1: G***; kibuzzard-6409D4D1
kibuzzard-6409D47A: G***; kibuzzard-6409D47A
kibuzzard-6409D460: G***; kibuzzard-6409D460

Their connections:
GND: C4#2.2, C10#2.2, C10#3.2, C10#4.2; also elsewhere on the board
Vbatout: C4#2.1; also elsewhere on the board
Vbatout12: C10#2.1, C10#3.1, C10#4.1; also elsewhere on the board

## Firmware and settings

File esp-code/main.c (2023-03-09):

#include "driver/gpio.h" 
#include "mqtt_client.h"
#include "esp_log.h"    
#include "esp_wifi.h"   
#include "esp_system.h"
#include "esp_event.h"
#include "nvs_flash.h"
#include "esp_netif.h"

#include "freertos/FreeRTOS.h"
#include "freertos/task.h"
#include "freertos/semphr.h"
#include "freertos/queue.h"
#include "freertos/event_groups.h"

//Wifi dependencies working
#define WIFI_CONNECTED_BIT BIT0
#define WIFI_FAIL_BIT      BIT1
static int s_retry_num = 0;
static EventGroupHandle_t s_wifi_event_group;
#define EXAMPLE_ESP_MAXIMUM_RETRY  5


#define LED_PIN GPIO_NUM_2

#define WIFI_SSID "devbit"
#define WIFI_PASS "Dr@@dloos!"

static esp_mqtt_client_handle_t client;


static uint8_t led_state = 0;
//

//led blink test working
void blink_led(void)
{
    gpio_set_level(LED_PIN, led_state);
}
//

//wifi event handler
static void event_handler(void* arg, esp_event_base_t event_base,
                                int32_t event_id, void* event_data)
{
    if (event_base == WIFI_EVENT && event_id == WIFI_EVENT_STA_START) {
        esp_wifi_connect();
    } else if (event_base == WIFI_EVENT && event_id == WIFI_EVENT_STA_DISCONNECTED) {
        if (s_retry_num < EXAMPLE_ESP_MAXIMUM_RETRY) {
            esp_wifi_connect();
            s_retry_num++;
            ESP_LOGI("WIFI", "retry to connect to the AP");
        } else {
            xEventGroupSetBits(s_wifi_event_group, WIFI_FAIL_BIT);
        }
        ESP_LOGI("WIFI","connect to the AP fail");
    } else if (event_base == IP_EVENT && event_id == IP_EVENT_STA_GOT_IP) {
        ip_event_got_ip_t* event = (ip_event_got_ip_t*) event_data;
        ESP_LOGI("WIFI", "got ip:" IPSTR, IP2STR(&event->ip_info.ip));
        s_retry_num = 0;
        xEventGroupSetBits(s_wifi_event_group, WIFI_CONNECTED_BIT);
    }
}
//

//Wifi setup
void wifi_init_sta(void)
{
    s_wifi_event_group = xEventGroupCreate();

    ESP_ERROR_CHECK(esp_netif_init());

    ESP_ERROR_CHECK(esp_event_loop_create_default());
    esp_netif_create_default_wifi_sta();

    esp_event_handler_instance_t instance_any_id;
    esp_event_handler_instance_t instance_got_ip;
    ESP_ERROR_CHECK(esp_event_handler_instance_register(WIFI_EVENT,
                                                        ESP_EVENT_ANY_ID,
                                                        &event_handler,
                                                        NULL,
                                                        &instance_any_id));
    ESP_ERROR_CHECK(esp_event_handler_instance_register(IP_EVENT,
                                                        IP_EVENT_STA_GOT_IP,
                                                       &event_handler,
                                                        NULL,
                                                        &instance_got_ip));

    wifi_init_config_t cfg = WIFI_INIT_CONFIG_DEFAULT();
    ESP_ERROR_CHECK(esp_wifi_init(&cfg));

    wifi_config_t wifi_config = {
        .sta = {
            .ssid = WIFI_SSID,
            .password = WIFI_PASS,
        },
    };
    ESP_ERROR_CHECK(esp_wifi_set_mode(WIFI_MODE_STA));
    ESP_ERROR_CHECK(esp_wifi_set_config(WIFI_IF_STA, &wifi_config));
    ESP_ERROR_CHECK(esp_wifi_start());
}
//

//mqtt event handler
static void mqtt_event_handler(void *handler_args, esp_event_base_t base, int32_t event_id, void *event_data)
{
    esp_mqtt_event_handle_t event = event_data;
    esp_mqtt_client_handle_t intrnclient = event->client;
    int msg_id;
    switch ((esp_mqtt_event_id_t)event_id) {
    case MQTT_EVENT_CONNECTED:
        ESP_LOGI("MQTT", "MQTT_EVENT_CONNECTED");
        msg_id = esp_mqtt_client_publish(intrnclient, "homeassistant/battery/state", handler_args, 0, 1, 0);
        ESP_LOGI("MQTT", "sent publish successful, msg_id=%d", msg_id);

        /*msg_id = esp_mqtt_client_subscribe(intrnclient, "/topic/qos0", 0);
        ESP_LOGI("MQTT", "sent subscribe successful, msg_id=%d", msg_id);*/

        /*msg_id = esp_mqtt_client_subscribe(intrnclient, "/topic/qos1", 1);
        ESP_LOGI("MQTT", "sent subscribe successful, msg_id=%d", msg_id);*/

        /*msg_id = esp_mqtt_client_unsubscribe(intrnclient, "/topic/qos1");
        ESP_LOGI("MQTT", "sent unsubscribe successful, msg_id=%d", msg_id);*/
        break;
    case MQTT_EVENT_DISCONNECTED:
        ESP_LOGI("MQTT", "MQTT_EVENT_DISCONNECTED");
        break;

    case MQTT_EVENT_SUBSCRIBED:
        /*ESP_LOGI("MQTT", "MQTT_EVENT_SUBSCRIBED, msg_id=%d", event->msg_id);
        msg_id = esp_mqtt_client_publish(intrnclient, "/topic/qos0", "data", 0, 0, 0);
        ESP_LOGI("MQTT", "sent publish successful, msg_id=%d", msg_id);*/
        break;
    case MQTT_EVENT_UNSUBSCRIBED:
        ESP_LOGI("MQTT", "MQTT_EVENT_UNSUBSCRIBED, msg_id=%d", event->msg_id);
        break;
    case MQTT_EVENT_PUBLISHED:
        ESP_LOGI("MQTT", "MQTT_EVENT_PUBLISHED, msg_id=%d", event->msg_id);
        break;
    case MQTT_EVENT_DATA:
        ESP_LOGI("MQTT", "MQTT_EVENT_DATA");
        printf("TOPIC=%.*s\r\n", event->topic_len, event->topic);
        printf("DATA=%.*s\r\n", event->data_len, event->data);
        break;
    case MQTT_EVENT_ERROR:
        ESP_LOGI("MQTT", "MQTT_EVENT_ERROR");
        break;
    default:
        ESP_LOGI("MQTT", "Other event id:%d", event->event_id);
        break;
    }
}
//

//mqtt setup
static void mqtt_app_start(void)
{
    esp_mqtt_client_config_t mqtt_cfg = {
        .broker.address.uri = "mqtt://10.10.78.77:1883",
    };

    client = esp_mqtt_client_init(&mqtt_cfg);
    /* The last argument may be used to pass data to the event handler, in this example mqtt_event_handler */
    esp_mqtt_client_register_event(client, ESP_EVENT_ANY_ID, mqtt_event_handler, NULL);
    esp_mqtt_client_start(client);
}
//

//mqtt publisher
static void mqtt_publish_task(char *message)
{
    int message_id;
    message_id = esp_mqtt_client_publish(client, "homeassistant/battery/state", message, 0, 0, 0);
    ESP_LOGI("MQTT", "Published message with ID %d: %s", message_id, message);
}


void app_main(void)
{
    //Wifi code working
    esp_err_t ret = nvs_flash_init();
    if (ret == ESP_ERR_NVS_NO_FREE_PAGES || ret == ESP_ERR_NVS_NEW_VERSION_FOUND) {
      ESP_ERROR_CHECK(nvs_flash_erase());
      ret = nvs_flash_init();
    }
    ESP_ERROR_CHECK(ret);

    wifi_init_sta();
    vTaskDelay(200);
    gpio_set_direction(LED_PIN, GPIO_MODE_OUTPUT);
    //

    //mqtt code
    /*ESP_ERROR_CHECK(esp_netif_init());
    ESP_ERROR_CHECK(esp_event_loop_create_default());*/

    mqtt_app_start();


    while (1)
    {
        //blinky led
        ESP_LOGI("ESP32", "Hello World!");
        ESP_LOGI("LED CONTROL", "Turning the LED %s!", led_state == true ? "ON" : "OFF");
        blink_led();
        led_state = !led_state;
        //
        //mqtt message publish
        char message[30];
        sprintf(message, "LED is %s!", led_state == true ? "ON" : "OFF");
        mqtt_publish_task(message);
        //
        vTaskDelay(100); // Add 1 tick delay (10 ms) so that current task does not starve idle task and trigger watchdog timer
    }
}

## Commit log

2023-03-02 Made Bom and schematics.
    [export_cart_20230302_225304.csv]
2023-03-02 Moved pcb files to folder
    [export_cart_20230302_225304.csv]
2023-03-07 switched setup and about page on header
2023-03-09 switched to purple theme
2023-03-09 Switched to only one layout (inside app.vue)
2023-03-09 switched drawer to end (right side)
2023-03-09 add pcb files
    [ControlleBord.csv, ControlleBord.kicad_pcb, ControlleBord.kicad_sch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]
2023-03-15 added dark filter over bg image
2023-03-16 adding sensor
2023-03-18 refining mqtt devices
2023-03-23 show all bluetooth devices
2023-03-23 fixing battery charge
2023-04-12 added first version of cdem device
2023-04-18 Added IO map and I2C adresses to Schemas
2023-04-20 adding more function to the connect button
2023-04-20 added some flowcharts
2023-04-27 add costum device name
2023-05-08 added device info to dev readme
2023-05-09 Worked on case
    [Base.0014.ipt, Base.ipt, Lid.0005.ipt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]
2023-05-09 Finished v1 of case
    [Base.0014.ipt, Base.0016.ipt, Base.ipt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]
2023-05-09 added stl version of case parts
    [Base.stl, Button.stl, Lid.stl]
2023-05-09 converted case to obj for use in blender
2023-05-10 rendered transparent image of case
2023-05-10 resized and changed file type case picture
2023-05-10 replaced picture case with transparent version
2023-05-10 Firmware flowchart bijwerken

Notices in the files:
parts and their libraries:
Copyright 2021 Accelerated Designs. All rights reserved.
